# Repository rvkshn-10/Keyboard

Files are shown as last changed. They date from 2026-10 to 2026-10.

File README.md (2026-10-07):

# Keyboard 
Hello, this is a Keyboard Project which was my first time developing a PCB, after numerous errors and attempts, I finally got it done thanks to the Half Life Program at Hack Club. 
Firmware for the Arduino is in the firmware folder, while the PCB and Schematic files are in the main folder. Inside of the keyboard61 folder you can find the fabrication files necessary to print the actual circuit board. The layout, and pictures have also been put there.

Here are some images of my work!
Project image 1
Project image 2
Project image 3
Project image 4
Project image 5
Project image 6
Project image 7
Project image 8
Project image 9
Project image 10
Project image 11
Project image 12
Project image 13
Project image 14
Project image 15
Project image 16
Project image 17
Project image 18
Project image 19

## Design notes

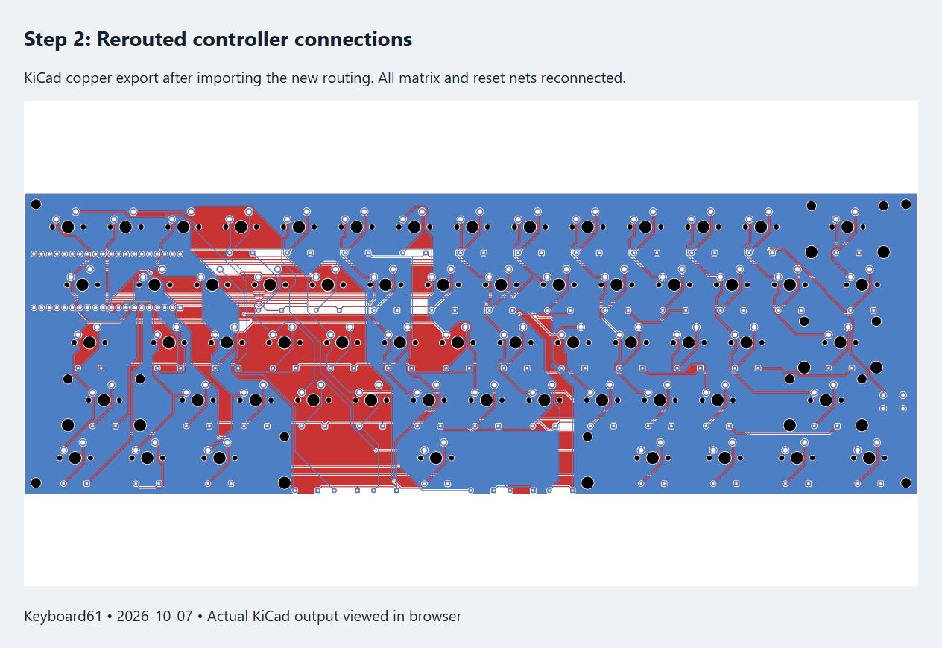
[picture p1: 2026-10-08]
keyboard61/inward-usb/screenshots/02-routing.jpg

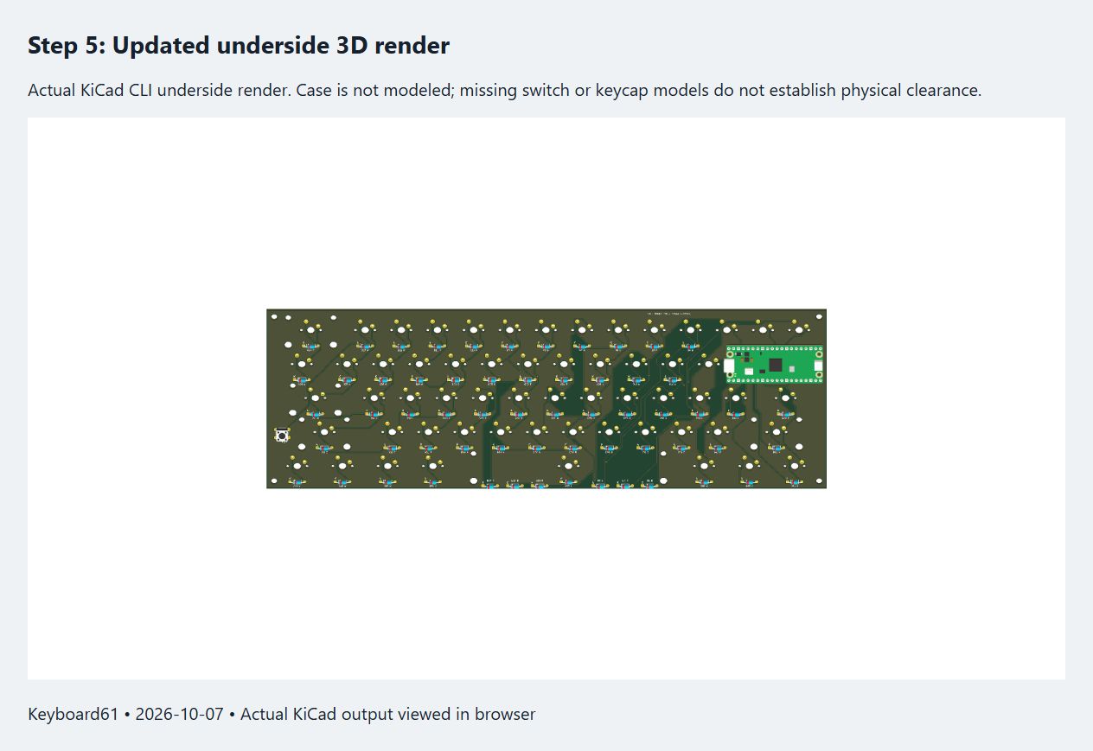
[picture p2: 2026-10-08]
keyboard61/inward-usb/screenshots/05-underside-3d.jpg

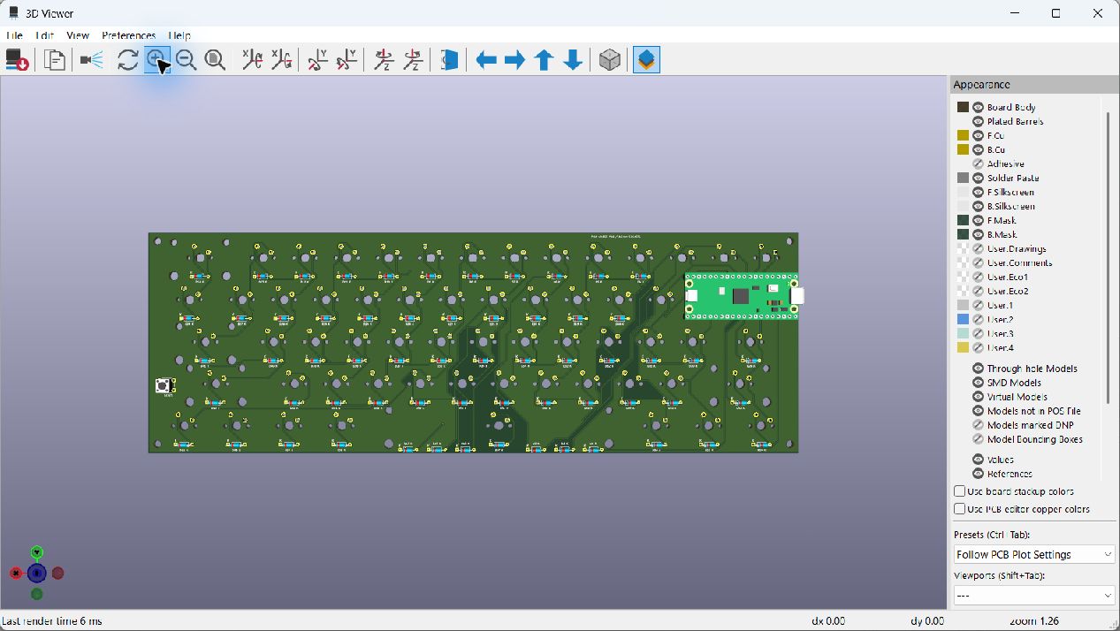
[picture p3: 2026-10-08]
keyboard61/compact-screenshots/02-finished-underside.jpg

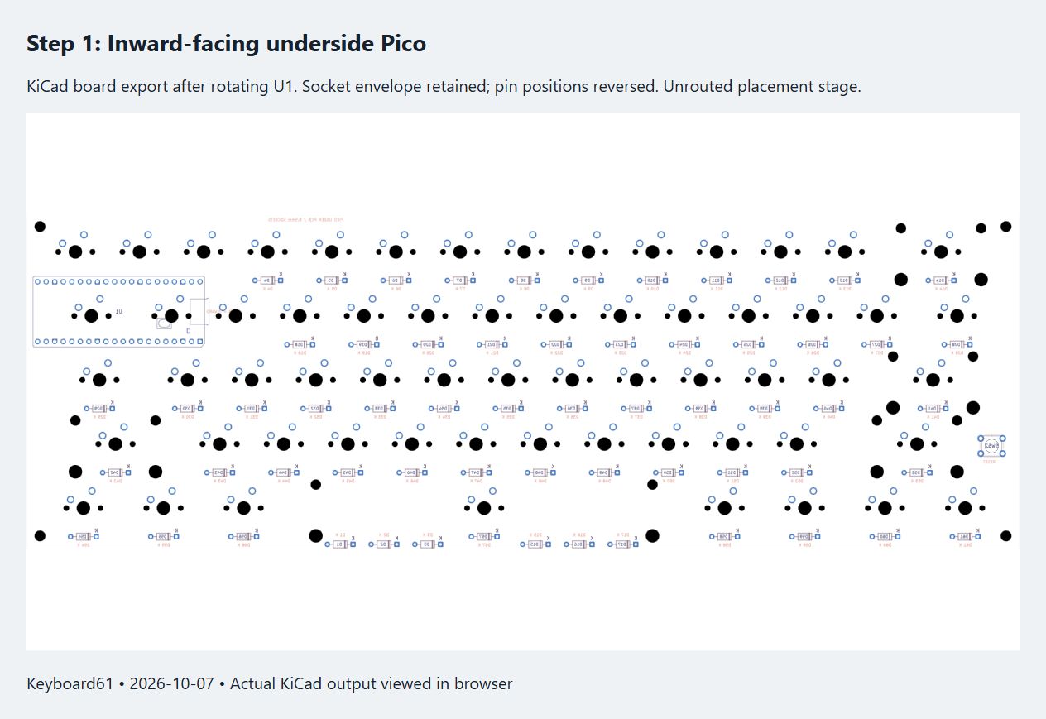
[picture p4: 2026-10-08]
keyboard61/inward-usb/screenshots/01-placement.jpg

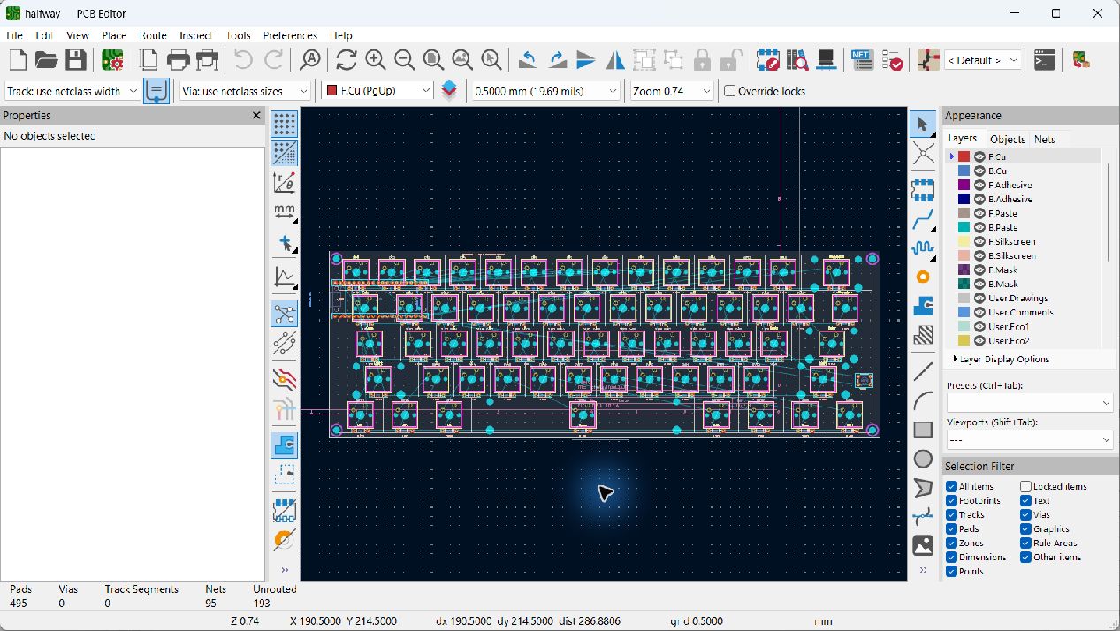
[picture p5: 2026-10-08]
keyboard61/compact-screenshots/01-placement.jpg

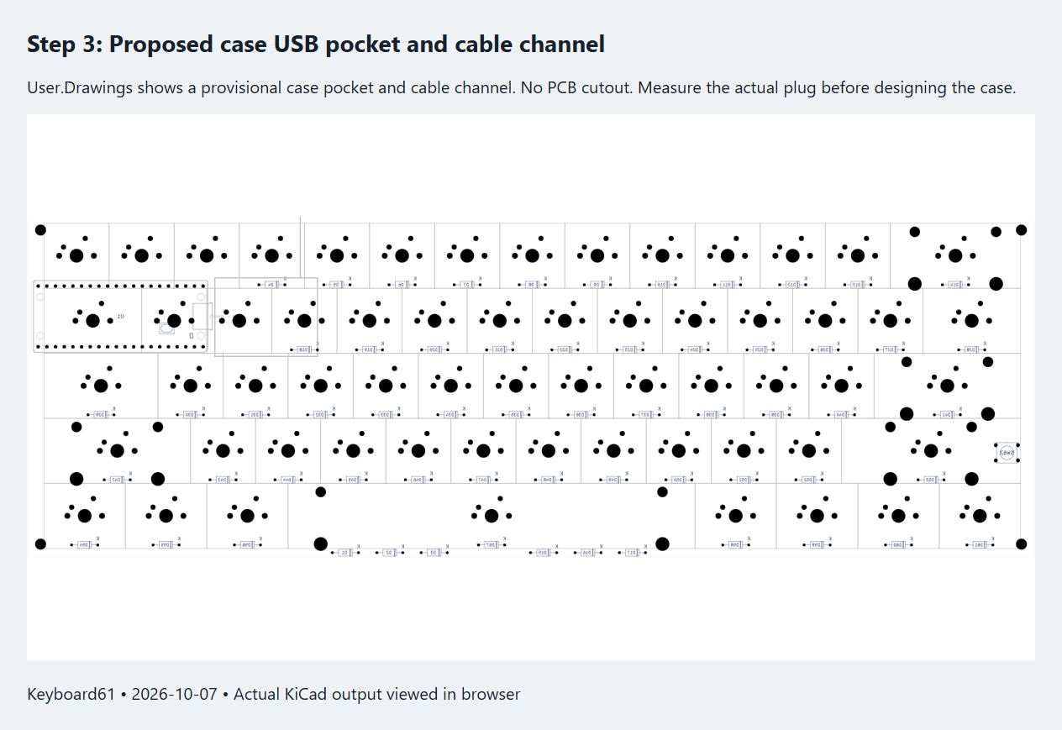
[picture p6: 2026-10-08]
keyboard61/inward-usb/screenshots/03-usb-pocket.jpg

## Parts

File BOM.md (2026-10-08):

# PC Keyboard – bill of materials

<!-- Generated by Half Life from project cmuvfkuo500di01qrszfxl69h. Edits here are overwritten on the next sync. -->
<!-- Generated: 2026-10-08T03:43:33.615Z -->

> [!NOTE]
> This parts list is mirrored from [Half Life](https://halflife.hackclub.com). Editing it here will not change the platform's copy, and the next sync overwrites this file.

| Week | Tier | Parts funding |
| --- | --- | --- |
| Week 1 | Tier 2 | $65.00 |

| Part | What it's for | Qty | Unit | Total | Vendor |
| --- | --- | --- | --- | --- | --- |
| [Keyboard PCB, Batch of 5](https://cart.jlcpcb.com/quote) | The PCB to control the keyboard | 1 | $31.15 | $31.15 | [JLCPCB](https://cart.jlcpcb.com/quote) |
| [onsemi 1N4148 DO-35 diode](https://www.digikey.com/en/products/detail/onsemi/1N4148/458603) | Prevent Keyboard from matrix ghosting | 61 | $0.04 | $2.44 | [Digikey](https://www.digikey.com/en/products/detail/onsemi/1N4148/458603) |
| [Raspberry Pi Pico H](https://www.digikey.com/en/products/detail/raspberry-pi/SC0917/16608257) | Scan the matrix, send USB outputs | 1 | $5.00 | $5.00 | [Digikey](https://www.digikey.com/en/products/detail/raspberry-pi/SC0917/16608257) |
| [Adafruit Pico female socket pair](https://www.digikey.com/en/products/detail/adafruit-industries-llc/5583/16688063) | Socket the Pico on the PCB | 1 | $0.95 | $0.95 | [Digikey](https://www.digikey.com/en/products/detail/adafruit-industries-llc/5583/16688063) |
| [Adafruit 4111 USB-A to Micro-B cable, 1 m](https://www.digikey.com/en/products/detail/adafruit-industries-llc/4111/9992197) | Connects the Pico to the PC | 1 | $3.95 | $3.95 | [DigiKey](https://www.digikey.com/en/products/detail/adafruit-industries-llc/4111/9992197) |
| **Parts subtotal** | — | — | — | **$43.49** | — |
| **Tax & shipping** | — | — | — | **$20.00** | — |
| **Total** | — | — | — | **$63.49** | — |

$1.51 left of the tier's funding.

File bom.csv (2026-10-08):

Part | Quantity | Unit Price | Total Price | Vendor | Vendor Name | Purpose | Specification | Price Status | Paid By
Keyboard PCB - batch of 5 | 1 | 31.15 | 31.15 | https://cart.jlcpcb.com/quote | JLCPCB | Connect the switches and Pico | keyboard61 compact underside-Pico revision; 295 x 100 mm; 2 layers; 1.6 mm FR4; 1 oz; green; lead-free HASL; 5 boards minimum; 1 used | USD 31.15 is the prior 295 x 168 mm size-based estimate; new 295 x 100 mm board requires a fresh fabrication quote; shipping and tax pending | Hack Club funding request
onsemi 1N4148 DO-35 diodes - 61-piece purchasing group | 1 | 2.57 | 2.57 | https://www.digikey.com/en/products/detail/onsemi/1N4148/458603 | DigiKey | Prevent keyboard matrix ghosting | Order 61 individual onsemi 1N4148 DO-35 diodes at USD 0.0422 each; grouped for cent-precision BOM import; 61 fitted; bend leads to 7.62 mm pitch | Listed USD price checked 2026-10-07; tax shipping and applicable tariffs excluded | Hack Club funding request
Raspberry Pi Pico H | 1 | 5.00 | 5.00 | https://www.digikey.com/en/products/detail/raspberry-pi/SC0917/16608257 | DigiKey | Scan the matrix and send USB key presses | SC0917; RP2040 original Pico H; pre-soldered male headers; micro-USB; matches existing Pico pin map | Listed USD price checked 2026-10-07; tax shipping and applicable tariffs excluded | Hack Club funding request
Adafruit Pico female socket pair | 1 | 0.95 | 0.95 | https://www.digikey.com/en/products/detail/adafruit-industries-llc/5583/16688063 | DigiKey | Socket the Pico on the PCB | Adafruit 5583; two standard-height 8.5 mm 1x20 female sockets; 2.54 mm pitch; mount on BACK; Pico H USB faces left; confirm actual enclosure and plug clearance | Listed USD price checked 2026-10-07; tax shipping and applicable tariffs excluded | Hack Club funding request

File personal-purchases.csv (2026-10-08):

Part | Quantity | Unit Price | Total Price | Vendor | Vendor Name | Purpose | Specification | Price Status | Paid By
Gateron Milky Yellow Pro V2 - pack of 70 | 1 | 19.99 | 19.99 | https://www.amazon.com/dp/B0BBPPP7HD | Amazon / CN GAMING | Detect each key press | 70 switches; 61 used and 9 spare; 5-pin PCB-mount MX stem; 50gf linear; soldered | USD price checked 2026-10-07; regular price; tax and shipping excluded | Personal purchase
SDYZ x XVX Gradient Green keycap set | 1 | 13.99 | 13.99 | https://www.amazon.com/dp/B0DNMV32L2 | Amazon / HITIME Shop | Provide surfaces for the 61 keys | Green; OEM doubleshot PBT; MX stems; standard ANSI 61-key sizes; 6.25u spacebar; regular non-Prime price | USD price checked 2026-10-07; regular price; tax and shipping excluded | Personal purchase
Chilkey WS Stupid snap-in stabilizer kit | 1 | 21.99 | 21.99 | https://www.amazon.com/dp/B0D2KMVVL3 | Amazon / Meletrix Direct | Support the five wide keys | Select 1.6 mm PCB version; four 2u and one 6.25u stabilizers required; use 6.25u wire; PCB snap-in; confirm hole geometry before fabrication | USD price checked 2026-10-07; regular price; tax and shipping excluded | Personal purchase
YOUFEN reset buttons - pack of 126 | 1 | 4.66 | 4.66 | https://www.amazon.com/dp/B0D5M2ZNSL | Amazon | Connect RUN to ground to reset the Pico | 6 x 6 x 5 mm four-pin through-hole tactile; one used; 125 spare; verify pin pitch against SW_PUSH_6mm | USD price checked 2026-10-07; regular price; tax and shipping excluded | Personal purchase
M3 nylon standoff and fastener kit - 600 pieces | 1 | 6.99 | 6.99 | https://www.amazon.com/dp/B0G3XCGSNV | Amazon / YILEGOU | Support the PCB above the desk | M3 nylon screws nuts and spacers; 6 to 20 mm lengths; four mounting holes; use suitable spacers for underside diode clearance; future custom enclosure deferred | USD price checked 2026-10-07; regular price; tax and shipping excluded | Personal purchase
Micro USB data cable - 3 ft | 1 | 5.99 | 5.99 | https://www.amazon.com/dp/B0BLL6BPGC | Amazon / Wancheng store | Power the Pico and carry USB keyboard data | Black; 3 ft; USB-A to micro-B; USB 2.0 480Mbps data sync; regular non-Prime buy-box price; one cable | USD price checked 2026-10-07; regular price; tax and shipping excluded | Personal purchase

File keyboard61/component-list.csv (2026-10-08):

Reference | Value | Footprint
D1 | 1N4148 | Diode_THT:D_DO-35_SOD27_P7.62mm_Horizontal
D2 | 1N4148 | Diode_THT:D_DO-35_SOD27_P7.62mm_Horizontal
D3 | 1N4148 | Diode_THT:D_DO-35_SOD27_P7.62mm_Horizontal
D4 | 1N4148 | Diode_THT:D_DO-35_SOD27_P7.62mm_Horizontal
D5 | 1N4148 | Diode_THT:D_DO-35_SOD27_P7.62mm_Horizontal
D6 | 1N4148 | Diode_THT:D_DO-35_SOD27_P7.62mm_Horizontal
D7 | 1N4148 | Diode_THT:D_DO-35_SOD27_P7.62mm_Horizontal
D8 | 1N4148 | Diode_THT:D_DO-35_SOD27_P7.62mm_Horizontal
D9 | 1N4148 | Diode_THT:D_DO-35_SOD27_P7.62mm_Horizontal
D10 | 1N4148 | Diode_THT:D_DO-35_SOD27_P7.62mm_Horizontal
D11 | 1N4148 | Diode_THT:D_DO-35_SOD27_P7.62mm_Horizontal
D12 | 1N4148 | Diode_THT:D_DO-35_SOD27_P7.62mm_Horizontal
D13 | 1N4148 | Diode_THT:D_DO-35_SOD27_P7.62mm_Horizontal
D14 | 1N4148 | Diode_THT:D_DO-35_SOD27_P7.62mm_Horizontal
D15 | 1N4148 | Diode_THT:D_DO-35_SOD27_P7.62mm_Horizontal
D16 | 1N4148 | Diode_THT:D_DO-35_SOD27_P7.62mm_Horizontal
D17 | 1N4148 | Diode_THT:D_DO-35_SOD27_P7.62mm_Horizontal
D18 | 1N4148 | Diode_THT:D_DO-35_SOD27_P7.62mm_Horizontal
D19 | 1N4148 | Diode_THT:D_DO-35_SOD27_P7.62mm_Horizontal
D20 | 1N4148 | Diode_THT:D_DO-35_SOD27_P7.62mm_Horizontal
D21 | 1N4148 | Diode_THT:D_DO-35_SOD27_P7.62mm_Horizontal
D22 | 1N4148 | Diode_THT:D_DO-35_SOD27_P7.62mm_Horizontal
D23 | 1N4148 | Diode_THT:D_DO-35_SOD27_P7.62mm_Horizontal
D24 | 1N4148 | Diode_THT:D_DO-35_SOD27_P7.62mm_Horizontal
D25 | 1N4148 | Diode_THT:D_DO-35_SOD27_P7.62mm_Horizontal
D26 | 1N4148 | Diode_THT:D_DO-35_SOD27_P7.62mm_Horizontal
D27 | 1N4148 | Diode_THT:D_DO-35_SOD27_P7.62mm_Horizontal
D28 | 1N4148 | Diode_THT:D_DO-35_SOD27_P7.62mm_Horizontal
D29 | 1N4148 | Diode_THT:D_DO-35_SOD27_P7.62mm_Horizontal
D30 | 1N4148 | Diode_THT:D_DO-35_SOD27_P7.62mm_Horizontal
D31 | 1N4148 | Diode_THT:D_DO-35_SOD27_P7.62mm_Horizontal
D32 | 1N4148 | Diode_THT:D_DO-35_SOD27_P7.62mm_Horizontal
D33 | 1N4148 | Diode_THT:D_DO-35_SOD27_P7.62mm_Horizontal
D34 | 1N4148 | Diode_THT:D_DO-35_SOD27_P7.62mm_Horizontal
D35 | 1N4148 | Diode_THT:D_DO-35_SOD27_P7.62mm_Horizontal
D36 | 1N4148 | Diode_THT:D_DO-35_SOD27_P7.62mm_Horizontal
D37 | 1N4148 | Diode_THT:D_DO-35_SOD27_P7.62mm_Horizontal
D38 | 1N4148 | Diode_THT:D_DO-35_SOD27_P7.62mm_Horizontal
D39 | 1N4148 | Diode_THT:D_DO-35_SOD27_P7.62mm_Horizontal
D40 | 1N4148 | Diode_THT:D_DO-35_SOD27_P7.62mm_Horizontal
D41 | 1N4148 | Diode_THT:D_DO-35_SOD27_P7.62mm_Horizontal
D42 | 1N4148 | Diode_THT:D_DO-35_SOD27_P7.62mm_Horizontal
D43 | 1N4148 | Diode_THT:D_DO-35_SOD27_P7.62mm_Horizontal
D44 | 1N4148 | Diode_THT:D_DO-35_SOD27_P7.62mm_Horizontal
D45 | 1N4148 | Diode_THT:D_DO-35_SOD27_P7.62mm_Horizontal
D46 | 1N4148 | Diode_THT:D_DO-35_SOD27_P7.62mm_Horizontal
D47 | 1N4148 | Diode_THT:D_DO-35_SOD27_P7.62mm_Horizontal
D48 | 1N4148 | Diode_THT:D_DO-35_SOD27_P7.62mm_Horizontal
D49 | 1N4148 | Diode_THT:D_DO-35_SOD27_P7.62mm_Horizontal
D50 | 1N4148 | Diode_THT:D_DO-35_SOD27_P7.62mm_Horizontal
D51 | 1N4148 | Diode_THT:D_DO-35_SOD27_P7.62mm_Horizontal
D52 | 1N4148 | Diode_THT:D_DO-35_SOD27_P7.62mm_Horizontal
D53 | 1N4148 | Diode_THT:D_DO-35_SOD27_P7.62mm_Horizontal
D54 | 1N4148 | Diode_THT:D_DO-35_SOD27_P7.62mm_Horizontal
D55 | 1N4148 | Diode_THT:D_DO-35_SOD27_P7.62mm_Horizontal
D56 | 1N4148 | Diode_THT:D_DO-35_SOD27_P7.62mm_Horizontal
D57 | 1N4148 | Diode_THT:D_DO-35_SOD27_P7.62mm_Horizontal
D58 | 1N4148 | Diode_THT:D_DO-35_SOD27_P7.62mm_Horizontal
D59 | 1N4148 | Diode_THT:D_DO-35_SOD27_P7.62mm_Horizontal
D60 | 1N4148 | Diode_THT:D_DO-35_SOD27_P7.62mm_Horizontal
D61 | 1N4148 | Diode_THT:D_DO-35_SOD27_P7.62mm_Horizontal
SW1 | Esc | Button_Switch_Keyboard:SW_Cherry_MX_1.00u_PCB
SW2 | 1 | Button_Switch_Keyboard:SW_Cherry_MX_1.00u_PCB
SW3 | 2 | Button_Switch_Keyboard:SW_Cherry_MX_1.00u_PCB
SW4 | 3 | Button_Switch_Keyboard:SW_Cherry_MX_1.00u_PCB
SW5 | 4 | Button_Switch_Keyboard:SW_Cherry_MX_1.00u_PCB
SW6 | 5 | Button_Switch_Keyboard:SW_Cherry_MX_1.00u_PCB
SW7 | 6 | Button_Switch_Keyboard:SW_Cherry_MX_1.00u_PCB
SW8 | 7 | Button_Switch_Keyboard:SW_Cherry_MX_1.00u_PCB
SW9 | 8 | Button_Switch_Keyboard:SW_Cherry_MX_1.00u_PCB
SW10 | 9 | Button_Switch_Keyboard:SW_Cherry_MX_1.00u_PCB
SW11 | 0 | Button_Switch_Keyboard:SW_Cherry_MX_1.00u_PCB
SW12 | - | Button_Switch_Keyboard:SW_Cherry_MX_1.00u_PCB
SW13 | = | Button_Switch_Keyboard:SW_Cherry_MX_1.00u_PCB
SW14 | Backspace | Button_Switch_Keyboard:SW_Cherry_MX_2.00u_PCB
SW15 | Tab | Keyboard61:SW_Cherry_MX_1.50u_PCB_SocketClearance
SW16 | Q | Keyboard61:SW_Cherry_MX_1.00u_PCB_SocketClearance
SW17 | W | Button_Switch_Keyboard:SW_Cherry_MX_1.00u_PCB
SW18 | E | Button_Switch_Keyboard:SW_Cherry_MX_1.00u_PCB
SW19 | R | Button_Switch_Keyboard:SW_Cherry_MX_1.00u_PCB
SW20 | T | Button_Switch_Keyboard:SW_Cherry_MX_1.00u_PCB
SW21 | Y | Button_Switch_Keyboard:SW_Cherry_MX_1.00u_PCB
SW22 | U | Button_Switch_Keyboard:SW_Cherry_MX_1.00u_PCB
SW23 | I | Button_Switch_Keyboard:SW_Cherry_MX_1.00u_PCB
SW24 | O | Button_Switch_Keyboard:SW_Cherry_MX_1.00u_PCB
SW25 | P | Button_Switch_Keyboard:SW_Cherry_MX_1.00u_PCB
SW26 | [ | Button_Switch_Keyboard:SW_Cherry_MX_1.00u_PCB
SW27 | ] | Button_Switch_Keyboard:SW_Cherry_MX_1.00u_PCB
SW28 | Backslash | Button_Switch_Keyboard:SW_Cherry_MX_1.50u_PCB
SW29 | Caps | Button_Switch_Keyboard:SW_Cherry_MX_1.75u_PCB
SW30 | A | Button_Switch_Keyboard:SW_Cherry_MX_1.00u_PCB
SW31 | S | Button_Switch_Keyboard:SW_Cherry_MX_1.00u_PCB
SW32 | D | Button_Switch_Keyboard:SW_Cherry_MX_1.00u_PCB
SW33 | F | Button_Switch_Keyboard:SW_Cherry_MX_1.00u_PCB
SW34 | G | Button_Switch_Keyboard:SW_Cherry_MX_1.00u_PCB
SW35 | H | Button_Switch_Keyboard:SW_Cherry_MX_1.00u_PCB
SW36 | J | Button_Switch_Keyboard:SW_Cherry_MX_1.00u_PCB
SW37 | K | Button_Switch_Keyboard:SW_Cherry_MX_1.00u_PCB
SW38 | L | Button_Switch_Keyboard:SW_Cherry_MX_1.00u_PCB
SW39 | ; | Button_Switch_Keyboard:SW_Cherry_MX_1.00u_PCB
SW40 | Quote | Button_Switch_Keyboard:SW_Cherry_MX_1.00u_PCB
SW41 | Enter | Button_Switch_Keyboard:SW_Cherry_MX_2.25u_PCB
SW42 | LShift | Button_Switch_Keyboard:SW_Cherry_MX_2.25u_PCB
SW43 | Z | Button_Switch_Keyboard:SW_Cherry_MX_1.00u_PCB
SW44 | X | Button_Switch_Keyboard:SW_Cherry_MX_1.00u_PCB
SW45 | C | Button_Switch_Keyboard:SW_Cherry_MX_1.00u_PCB
SW46 | V | Button_Switch_Keyboard:SW_Cherry_MX_1.00u_PCB
SW47 | B | Button_Switch_Keyboard:SW_Cherry_MX_1.00u_PCB
SW48 | N | Button_Switch_Keyboard:SW_Cherry_MX_1.00u_PCB
SW49 | M | Button_Switch_Keyboard:SW_Cherry_MX_1.00u_PCB
SW50 | , | Button_Switch_Keyboard:SW_Cherry_MX_1.00u_PCB
SW51 | . | Button_Switch_Keyboard:SW_Cherry_MX_1.00u_PCB
SW52 | / | Button_Switch_Keyboard:SW_Cherry_MX_1.00u_PCB
SW53 | RShift | Button_Switch_Keyboard:SW_Cherry_MX_2.75u_PCB
SW54 | LCtrl | Button_Switch_Keyboard:SW_Cherry_MX_1.25u_PCB
SW55 | LWin | Button_Switch_Keyboard:SW_Cherry_MX_1.25u_PCB
SW56 | LAlt | Button_Switch_Keyboard:SW_Cherry_MX_1.25u_PCB
SW57 | Space | Button_Switch_Keyboard:SW_Cherry_MX_6.25u_PCB
SW58 | RAlt | Button_Switch_Keyboard:SW_Cherry_MX_1.25u_PCB
SW59 | Fn | Button_Switch_Keyboard:SW_Cherry_MX_1.25u_PCB
SW60 | Menu | Button_Switch_Keyboard:SW_Cherry_MX_1.25u_PCB
SW61 | RCtrl | Button_Switch_Keyboard:SW_Cherry_MX_1.25u_PCB
SW62 | RESET | Button_Switch_THT:SW_PUSH_6mm
U1 | Raspberry Pi Pico | Keyboard61:Pico_H_Bottom_Sockets_8_5mm

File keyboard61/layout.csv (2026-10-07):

reference | diode | key | row | col | x_u | y_u | width_u | footprint
SW1 | D1 | Esc | 0 | 0 | 0 | 0 | 1 | Button_Switch_Keyboard:SW_Cherry_MX_1.00u_PCB
SW2 | D2 | 1 | 0 | 1 | 1 | 0 | 1 | Button_Switch_Keyboard:SW_Cherry_MX_1.00u_PCB
SW3 | D3 | 2 | 0 | 2 | 2 | 0 | 1 | Button_Switch_Keyboard:SW_Cherry_MX_1.00u_PCB
SW4 | D4 | 3 | 0 | 3 | 3 | 0 | 1 | Button_Switch_Keyboard:SW_Cherry_MX_1.00u_PCB
SW5 | D5 | 4 | 0 | 4 | 4 | 0 | 1 | Button_Switch_Keyboard:SW_Cherry_MX_1.00u_PCB
SW6 | D6 | 5 | 0 | 5 | 5 | 0 | 1 | Button_Switch_Keyboard:SW_Cherry_MX_1.00u_PCB
SW7 | D7 | 6 | 0 | 6 | 6 | 0 | 1 | Button_Switch_Keyboard:SW_Cherry_MX_1.00u_PCB
SW8 | D8 | 7 | 0 | 7 | 7 | 0 | 1 | Button_Switch_Keyboard:SW_Cherry_MX_1.00u_PCB
SW9 | D9 | 8 | 0 | 8 | 8 | 0 | 1 | Button_Switch_Keyboard:SW_Cherry_MX_1.00u_PCB
SW10 | D10 | 9 | 0 | 9 | 9 | 0 | 1 | Button_Switch_Keyboard:SW_Cherry_MX_1.00u_PCB
SW11 | D11 | 0 | 0 | 10 | 10 | 0 | 1 | Button_Switch_Keyboard:SW_Cherry_MX_1.00u_PCB
SW12 | D12 | - | 0 | 11 | 11 | 0 | 1 | Button_Switch_Keyboard:SW_Cherry_MX_1.00u_PCB
SW13 | D13 | = | 0 | 12 | 12 | 0 | 1 | Button_Switch_Keyboard:SW_Cherry_MX_1.00u_PCB
SW14 | D14 | Backspace | 0 | 13 | 13 | 0 | 2 | Button_Switch_Keyboard:SW_Cherry_MX_2.00u_PCB
SW15 | D15 | Tab | 1 | 0 | 0 | 1 | 1.5 | Button_Switch_Keyboard:SW_Cherry_MX_1.50u_PCB
SW16 | D16 | Q | 1 | 1 | 1.5 | 1 | 1 | Button_Switch_Keyboard:SW_Cherry_MX_1.00u_PCB
SW17 | D17 | W | 1 | 2 | 2.5 | 1 | 1 | Button_Switch_Keyboard:SW_Cherry_MX_1.00u_PCB
SW18 | D18 | E | 1 | 3 | 3.5 | 1 | 1 | Button_Switch_Keyboard:SW_Cherry_MX_1.00u_PCB
SW19 | D19 | R | 1 | 4 | 4.5 | 1 | 1 | Button_Switch_Keyboard:SW_Cherry_MX_1.00u_PCB
SW20 | D20 | T | 1 | 5 | 5.5 | 1 | 1 | Button_Switch_Keyboard:SW_Cherry_MX_1.00u_PCB
SW21 | D21 | Y | 1 | 6 | 6.5 | 1 | 1 | Button_Switch_Keyboard:SW_Cherry_MX_1.00u_PCB
SW22 | D22 | U | 1 | 7 | 7.5 | 1 | 1 | Button_Switch_Keyboard:SW_Cherry_MX_1.00u_PCB
SW23 | D23 | I | 1 | 8 | 8.5 | 1 | 1 | Button_Switch_Keyboard:SW_Cherry_MX_1.00u_PCB
SW24 | D24 | O | 1 | 9 | 9.5 | 1 | 1 | Button_Switch_Keyboard:SW_Cherry_MX_1.00u_PCB
SW25 | D25 | P | 1 | 10 | 10.5 | 1 | 1 | Button_Switch_Keyboard:SW_Cherry_MX_1.00u_PCB
SW26 | D26 | [ | 1 | 11 | 11.5 | 1 | 1 | Button_Switch_Keyboard:SW_Cherry_MX_1.00u_PCB
SW27 | D27 | ] | 1 | 12 | 12.5 | 1 | 1 | Button_Switch_Keyboard:SW_Cherry_MX_1.00u_PCB
SW28 | D28 | Backslash | 1 | 13 | 13.5 | 1 | 1.5 | Button_Switch_Keyboard:SW_Cherry_MX_1.50u_PCB
SW29 | D29 | Caps | 2 | 0 | 0 | 2 | 1.75 | Button_Switch_Keyboard:SW_Cherry_MX_1.75u_PCB
SW30 | D30 | A | 2 | 1 | 1.75 | 2 | 1 | Button_Switch_Keyboard:SW_Cherry_MX_1.00u_PCB
SW31 | D31 | S | 2 | 2 | 2.75 | 2 | 1 | Button_Switch_Keyboard:SW_Cherry_MX_1.00u_PCB
SW32 | D32 | D | 2 | 3 | 3.75 | 2 | 1 | Button_Switch_Keyboard:SW_Cherry_MX_1.00u_PCB
SW33 | D33 | F | 2 | 4 | 4.75 | 2 | 1 | Button_Switch_Keyboard:SW_Cherry_MX_1.00u_PCB
SW34 | D34 | G | 2 | 5 | 5.75 | 2 | 1 | Button_Switch_Keyboard:SW_Cherry_MX_1.00u_PCB
SW35 | D35 | H | 2 | 6 | 6.75 | 2 | 1 | Button_Switch_Keyboard:SW_Cherry_MX_1.00u_PCB
SW36 | D36 | J | 2 | 7 | 7.75 | 2 | 1 | Button_Switch_Keyboard:SW_Cherry_MX_1.00u_PCB
SW37 | D37 | K | 2 | 8 | 8.75 | 2 | 1 | Button_Switch_Keyboard:SW_Cherry_MX_1.00u_PCB
SW38 | D38 | L | 2 | 9 | 9.75 | 2 | 1 | Button_Switch_Keyboard:SW_Cherry_MX_1.00u_PCB
SW39 | D39 | ; | 2 | 10 | 10.75 | 2 | 1 | Button_Switch_Keyboard:SW_Cherry_MX_1.00u_PCB
SW40 | D40 | Quote | 2 | 11 | 11.75 | 2 | 1 | Button_Switch_Keyboard:SW_Cherry_MX_1.00u_PCB
SW41 | D41 | Enter | 2 | 12 | 12.75 | 2 | 2.25 | Button_Switch_Keyboard:SW_Cherry_MX_2.25u_PCB
SW42 | D42 | LShift | 3 | 0 | 0 | 3 | 2.25 | Button_Switch_Keyboard:SW_Cherry_MX_2.25u_PCB
SW43 | D43 | Z | 3 | 1 | 2.25 | 3 | 1 | Button_Switch_Keyboard:SW_Cherry_MX_1.00u_PCB
SW44 | D44 | X | 3 | 2 | 3.25 | 3 | 1 | Button_Switch_Keyboard:SW_Cherry_MX_1.00u_PCB
SW45 | D45 | C | 3 | 3 | 4.25 | 3 | 1 | Button_Switch_Keyboard:SW_Cherry_MX_1.00u_PCB
SW46 | D46 | V | 3 | 4 | 5.25 | 3 | 1 | Button_Switch_Keyboard:SW_Cherry_MX_1.00u_PCB
SW47 | D47 | B | 3 | 5 | 6.25 | 3 | 1 | Button_Switch_Keyboard:SW_Cherry_MX_1.00u_PCB
SW48 | D48 | N | 3 | 6 | 7.25 | 3 | 1 | Button_Switch_Keyboard:SW_Cherry_MX_1.00u_PCB
SW49 | D49 | M | 3 | 7 | 8.25 | 3 | 1 | Button_Switch_Keyboard:SW_Cherry_MX_1.00u_PCB
SW50 | D50 | , | 3 | 8 | 9.25 | 3 | 1 | Button_Switch_Keyboard:SW_Cherry_MX_1.00u_PCB
SW51 | D51 | . | 3 | 9 | 10.25 | 3 | 1 | Button_Switch_Keyboard:SW_Cherry_MX_1.00u_PCB
SW52 | D52 | / | 3 | 10 | 11.25 | 3 | 1 | Button_Switch_Keyboard:SW_Cherry_MX_1.00u_PCB
SW53 | D53 | RShift | 3 | 11 | 12.25 | 3 | 2.75 | Button_Switch_Keyboard:SW_Cherry_MX_2.75u_PCB
SW54 | D54 | LCtrl | 4 | 0 | 0 | 4 | 1.25 | Button_Switch_Keyboard:SW_Cherry_MX_1.25u_PCB
SW55 | D55 | LWin | 4 | 1 | 1.25 | 4 | 1.25 | Button_Switch_Keyboard:SW_Cherry_MX_1.25u_PCB
SW56 | D56 | LAlt | 4 | 2 | 2.5 | 4 | 1.25 | Button_Switch_Keyboard:SW_Cherry_MX_1.25u_PCB
SW57 | D57 | Space | 4 | 3 | 3.75 | 4 | 6.25 | Button_Switch_Keyboard:SW_Cherry_MX_6.25u_PCB
SW58 | D58 | RAlt | 4 | 4 | 10.0 | 4 | 1.25 | Button_Switch_Keyboard:SW_Cherry_MX_1.25u_PCB
SW59 | D59 | Fn | 4 | 5 | 11.25 | 4 | 1.25 | Button_Switch_Keyboard:SW_Cherry_MX_1.25u_PCB
SW60 | D60 | Menu | 4 | 6 | 12.5 | 4 | 1.25 | Button_Switch_Keyboard:SW_Cherry_MX_1.25u_PCB
SW61 | D61 | RCtrl | 4 | 7 | 13.75 | 4 | 1.25 | Button_Switch_Keyboard:SW_Cherry_MX_1.25u_PCB

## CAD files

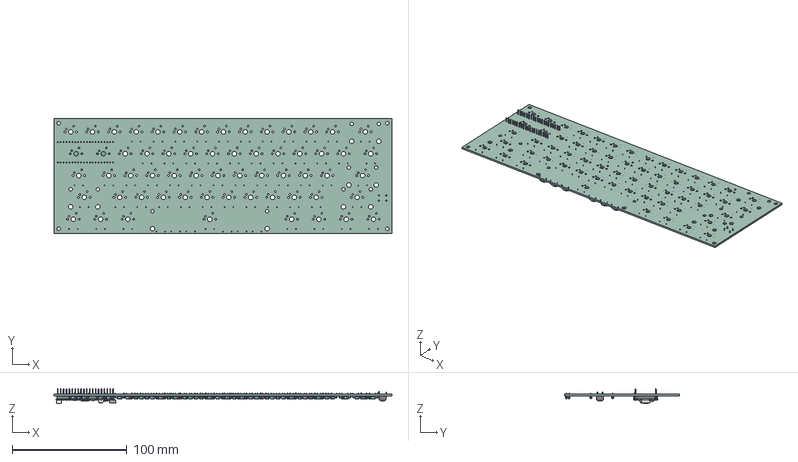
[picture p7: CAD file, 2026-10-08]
keyboard61/keyboard61.step
295.0 x 100.0 x 12.8 mm
D_DO-35_SOD27_P7.62mm_Horizontal x 61
RaspberryPi_Pico_H_Module_KiCad
RaspberryPi_Pico_Header_DIP-40_H2.54mm_KiCad
SW_PUSH_6mm
finished_PCB

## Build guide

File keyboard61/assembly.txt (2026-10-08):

PCB revision: compact underside Pico, 2026-10-07
Board: 295 x 100 mm, x45..340 y113..213, 1.6 mm FR4.
61 original key positions and GPIO assignments preserved. Firmware unchanged.
Pico H and reset switch fitted on BACK. Switches on FRONT.
Fit the two standard-height 8.5 mm 1x20 female sockets on BACK, matching pad 1.
Pico USB faces RIGHT, toward the keyboard center, underneath the PCB.
No USB extension cable is required by this revision.
Plan an accessible pocket in the CASE underside for inserting a normal Micro-B plug.
The proposed channel leads toward the edge above the number keys.
User.Drawings is a case-planning sketch, not copper or a PCB cutout.
Pocket envelope and channel are provisional; measure the real plug before case design.
Keep the cable and slack clear of switch pins, diode leads and mounting fasteners.
Allow cable bend radius and strain relief; never force a bend directly at the connector.
Leave at least 15 mm below the keyboard PCB as a preliminary enclosure allowance;
verify the actual Pico, USB plug and socket assembly before making the case.
Diodes D1,D2,D3,D15,D16,D17 remain beneath the spacebar area; follow K marks.
Underside Pico BOOTSEL and reset must remain accessible through the case.
KiCad DRC: 0 violations, 0 unconnected, 0 schematic parity issues; no exclusions.
KiCad schematic ERC: 0 violations. Hardware has not been assembled or tested.
PCB fabrication price and shipping must be re-quoted for the new dimensions.

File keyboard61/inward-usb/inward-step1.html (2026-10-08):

# Step 1: Inward-facing underside Pico

KiCad board export after rotating U1. Socket envelope retained; pin positions reversed. Unrouted placement stage.



Keyboard61 • 2026-10-07 • Actual KiCad output viewed in browser

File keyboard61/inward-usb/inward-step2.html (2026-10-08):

# Step 2: Rerouted controller connections

KiCad copper export after importing the new routing. All matrix and reset nets reconnected.



Keyboard61 • 2026-10-07 • Actual KiCad output viewed in browser

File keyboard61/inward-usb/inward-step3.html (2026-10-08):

# Step 3: Proposed case USB pocket and cable channel

User.Drawings shows a provisional case pocket and cable channel. No PCB cutout. Measure the actual plug before designing the case.



Keyboard61 • 2026-10-07 • Actual KiCad output viewed in browser

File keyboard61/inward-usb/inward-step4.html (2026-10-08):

# Step 4: KiCad electrical and layout checks

Actual KiCad CLI check results from the revised board and schematic. Default ignored check categories remain listed in the JSON report.

KiCad 10.0.6
PCB DRC: 0 violations
Unconnected items: 0
Schematic parity: 0 issues

ERC report (2026-10-07T20:56:49, Encoding UTF8)
Report includes: Errors, Warnings

***** Sheet /

 ** ERC messages: 0  Errors 0  Warnings 0

 ** Ignored checks:
    - Global label only appears once in the schematic
    - Four connection points are joined together
    - SPICE model issue
    - Assigned footprint doesn't match footprint filters

Keyboard61 • 2026-10-07 • Actual KiCad output viewed in browser

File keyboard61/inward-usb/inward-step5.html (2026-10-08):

# Step 5: Updated underside 3D render

Actual KiCad CLI underside render. Case is not modeled; missing switch or keycap models do not establish physical clearance.

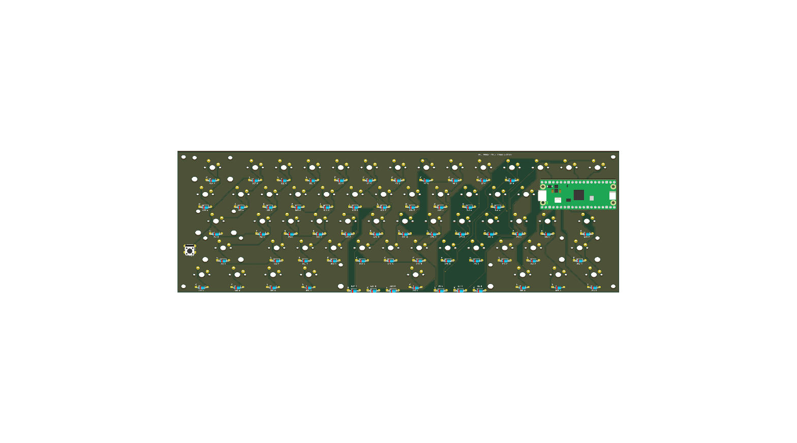
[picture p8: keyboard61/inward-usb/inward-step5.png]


Keyboard61 • 2026-10-07 • Actual KiCad output viewed in browser

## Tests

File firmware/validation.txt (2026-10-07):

PASS: A press and release
PASS: Shift+A and release
PASS: Fn+1 sends F1
PASS: Fn+I sends Up
PASS: Fn released before held F1
PASS: Unused matrix slot sends nothing
PASS: Menu key usage 0x65
PASS: 19 GPIO pins, COL2ROW, 61 occupied / 9 unused, 2 x 70 keymaps
Desktop simulation only; Pico USB, wiring and debounce require hardware testing.

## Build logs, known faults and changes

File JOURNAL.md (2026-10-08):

# PC Keyboard – devlog

<!-- Generated by Half Life from project cmuvfkuo500di01qrszfxl69h. Edits here are overwritten on the next sync. -->
<!-- Generated: 2026-10-08T03:15:25.698Z -->

> [!NOTE]
> This devlog is mirrored from [Half Life](https://halflife.hackclub.com). Editing it here will not change the platform's copy, and the next sync overwrites this file.

> A QWERTY wiredkeyboard

| Week | Tier | Hours logged | Entries |
| --- | --- | --- | --- |
| Week 1 | Tier 2 | 26.5h | 3 |

## Contents

1. [2026-10-06 – October 6](#2026-10-06-october-6)
2. [2026-10-07 – October 7](#2026-10-07-october-7)
3. [2026-10-07 – October 8](#2026-10-07-october-8)

## Design

### 2026-10-06 – October 6

**9.5h**

October 6

Though this was my first time designing a PCB, I still ended up creating a very basic Schematic. I originally began by following a GitHub tutorial, but that got quickly got too confusing, so I restarted  and began with finding KiCad Footprint Libraries and figuring out the electronics theory.

01-matrix-research
This was the Matrix Research I had to complete

To find the Libraries, I had to hunt down custom ones for Cherry MX switches, looking up the dimensions of a 1U keycap spacing, and looking into the pinout of an Arduino Pro Micro, but I later changed this to a Raspberry Pi



To understand the electronics theory, I had to research Keyboard matric functions, I also learned that I needed a 1N4148 diode next to every single switch to prevent something called ghosting. I also needed to know which way the electrical current flows in the PCB. I also learned how to use Global Labels to keep nets clean.


I also completed the 61 key ANSI layout as part of the placement plan along with matrix coordinate on each key

Later I found out that I didn't need a custom library, so I used the kicad ones, so I installed the kicad footprint verification


It took me a while to get to this stage at the pace I was working, and this was my first switch and anti-ghosting diode, and I followed the same method for each key


My next step was the number keys of 14 switch diode pairs, following the same COL to switch to diode anode; diode cathode to ROW


I later individually created each of the following keys and typed up the following information to specify which was which


My next step was  working with the Raspberry Pi Pico Controller and GPIO net labels, where I attached all labels and rows


By this point after many errors I made accidentally and going back and forth, I completed the full schematic


I later realized I missed something, I had to set up the Reset circuit and firmware flashing mode to use the onboard BOOTSEL button


### 2026-10-07 – October 7

**10h**

October 7

Now I began the actual PCB Portion. For PCB Layout, routing, and vias. I placed grid components, set up custom user grids and manual trace routing. I had to figure out how to route lines on both the front and back copper layers and sue plated holes (vias) to leapfrog the intersecting wires without short circuiting the board. I next had to do DRC Troubleshooting and Manufacturing setup, I threw quite a bit of errors, so I had to define an Edge.Cuts layer to outline the physical board, and I manually set up a copper filled zone to isolate electrical traces


I created my board outline, and the space above is reserved for the controller, the boundary was 295x168mm


I created my first switch row of 14 footprints using 19.05mm key spacing


Next I completed the remaining 61 switches in ANSI layout including the spacebar where the key is the center.


One 1N4148 diode was placed on each switch, on the back of the board between key rows, this is to prevent ghost key presses, an issue that arised for many other people that completed this project


I added the Pico footprint, reset button, and 4 3.2mm mounting holes. I still need to plan to create a casing for the keyboard based on this


Copper tracks were added between each switch and the diode, these are the individual key connections before the shared matrix wiring is completed


With this step I achieved complete signal routing as row and column connections were routed to Pico across front and back copper layers. The vias connect tracks between layers where they were needed


Filled ground planes on both sides of the PCB. KiCad did leave some clearance around unrelated tracks and pads. Apparently the thermal connections link ground pads to the pours while making the pads easier to solder


I created a Key legend, board identification, assembly instructions to the silkscreen layers. After this there were some errors, which I ended up fixing


KiCad displayed the PCB in it's 3D viewer. For some reason the CherryMX model's didn't work so I would need to troubleshoot why the keycaps and switches are absent

Honest Note: I did use ChatGPT to help me understand the process when designing this PCB, along with helping me fix whatever errors I had. It also helped me take screenshots as my windows computer wouldn't let me on my wireless keyboard, therefore the blue cursor in several screenshots.

The next hour-ish (1-1.5) I've dedicated to creating firmware, I used Python ( a language I am quite good at ) using KMK, which runs on the CircuitPython on the Raspberry Pi Pico. I configured Matrix Wiring, Diode Direction, Key Layout, Fn Layer, USB Keyboard mode. I then ran desktop simulations for typing, wrote and tested the firmware files.

After this I spent the next 0.5 hour updating everything to github, and pushing changes to get stuff done.

### 2026-10-07 – October 8

**7h**

October 8

I had a new idea, what if we move the extra space on top and the pico a better spot to take less space. This would also look cleaner in the overall design


This change reduce the size 295x100mm and the Pico is now underneath the keyboard, with the USB facing left to connect to the PC. I thought about this so to make it cleaner, the Pico was moved facing the USB to the top. But this caused another problem, the Pico header pins ran into the switch mounting areas, so the cleanest solution was to keep the Pico underneath and use a short USB extension to a port on the case's edge above the number keys. Or we could create a short recessed pocket underneath the keyboard which works equally as well


The next step was to rotate the underside Pico inward. To do this I positioned it's USB port toward the keyboard's center and check clearance around the switch pins


I then had to reroute the controller connections, by reconnecting the matrix and reset circuit after changing the Pico orientation.


Nest I had to plan the USB pocket and cable channel by drawing the proposed case opened and space for insert the plug with the cable exiting above the number keys.


Then I had to refill the copper zones and run DRC, for which I had to fix any clearance or connection errors introduced by the changes and then capture the following results in the JSON report.


Finally I had to take a look at the updated underside in 3D to check on the controller placement and export new Gerbers and drill files for the new and revised board.


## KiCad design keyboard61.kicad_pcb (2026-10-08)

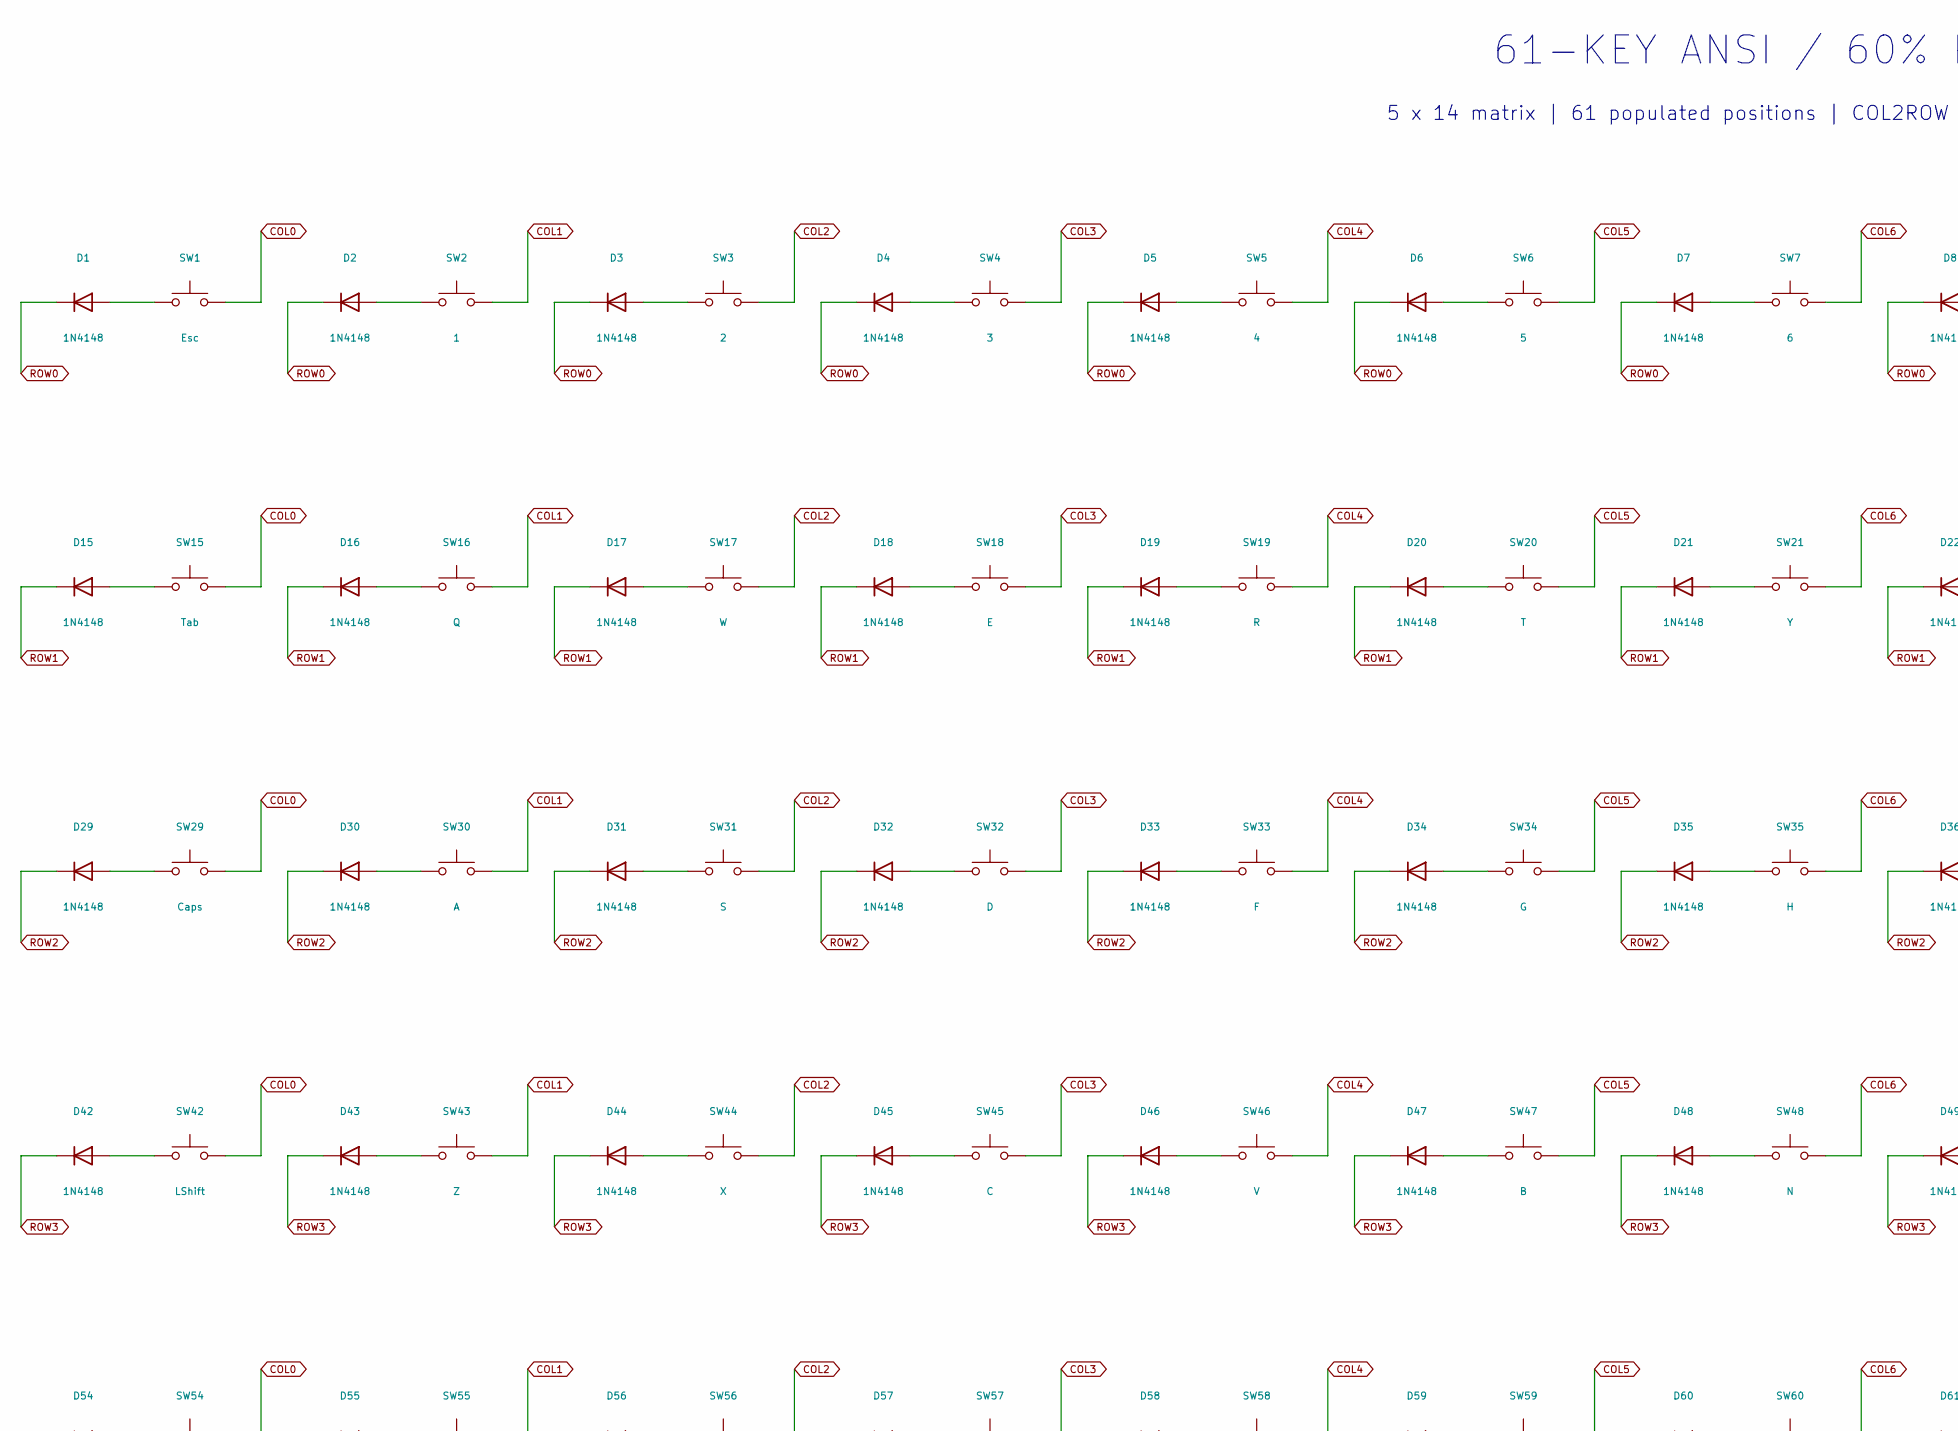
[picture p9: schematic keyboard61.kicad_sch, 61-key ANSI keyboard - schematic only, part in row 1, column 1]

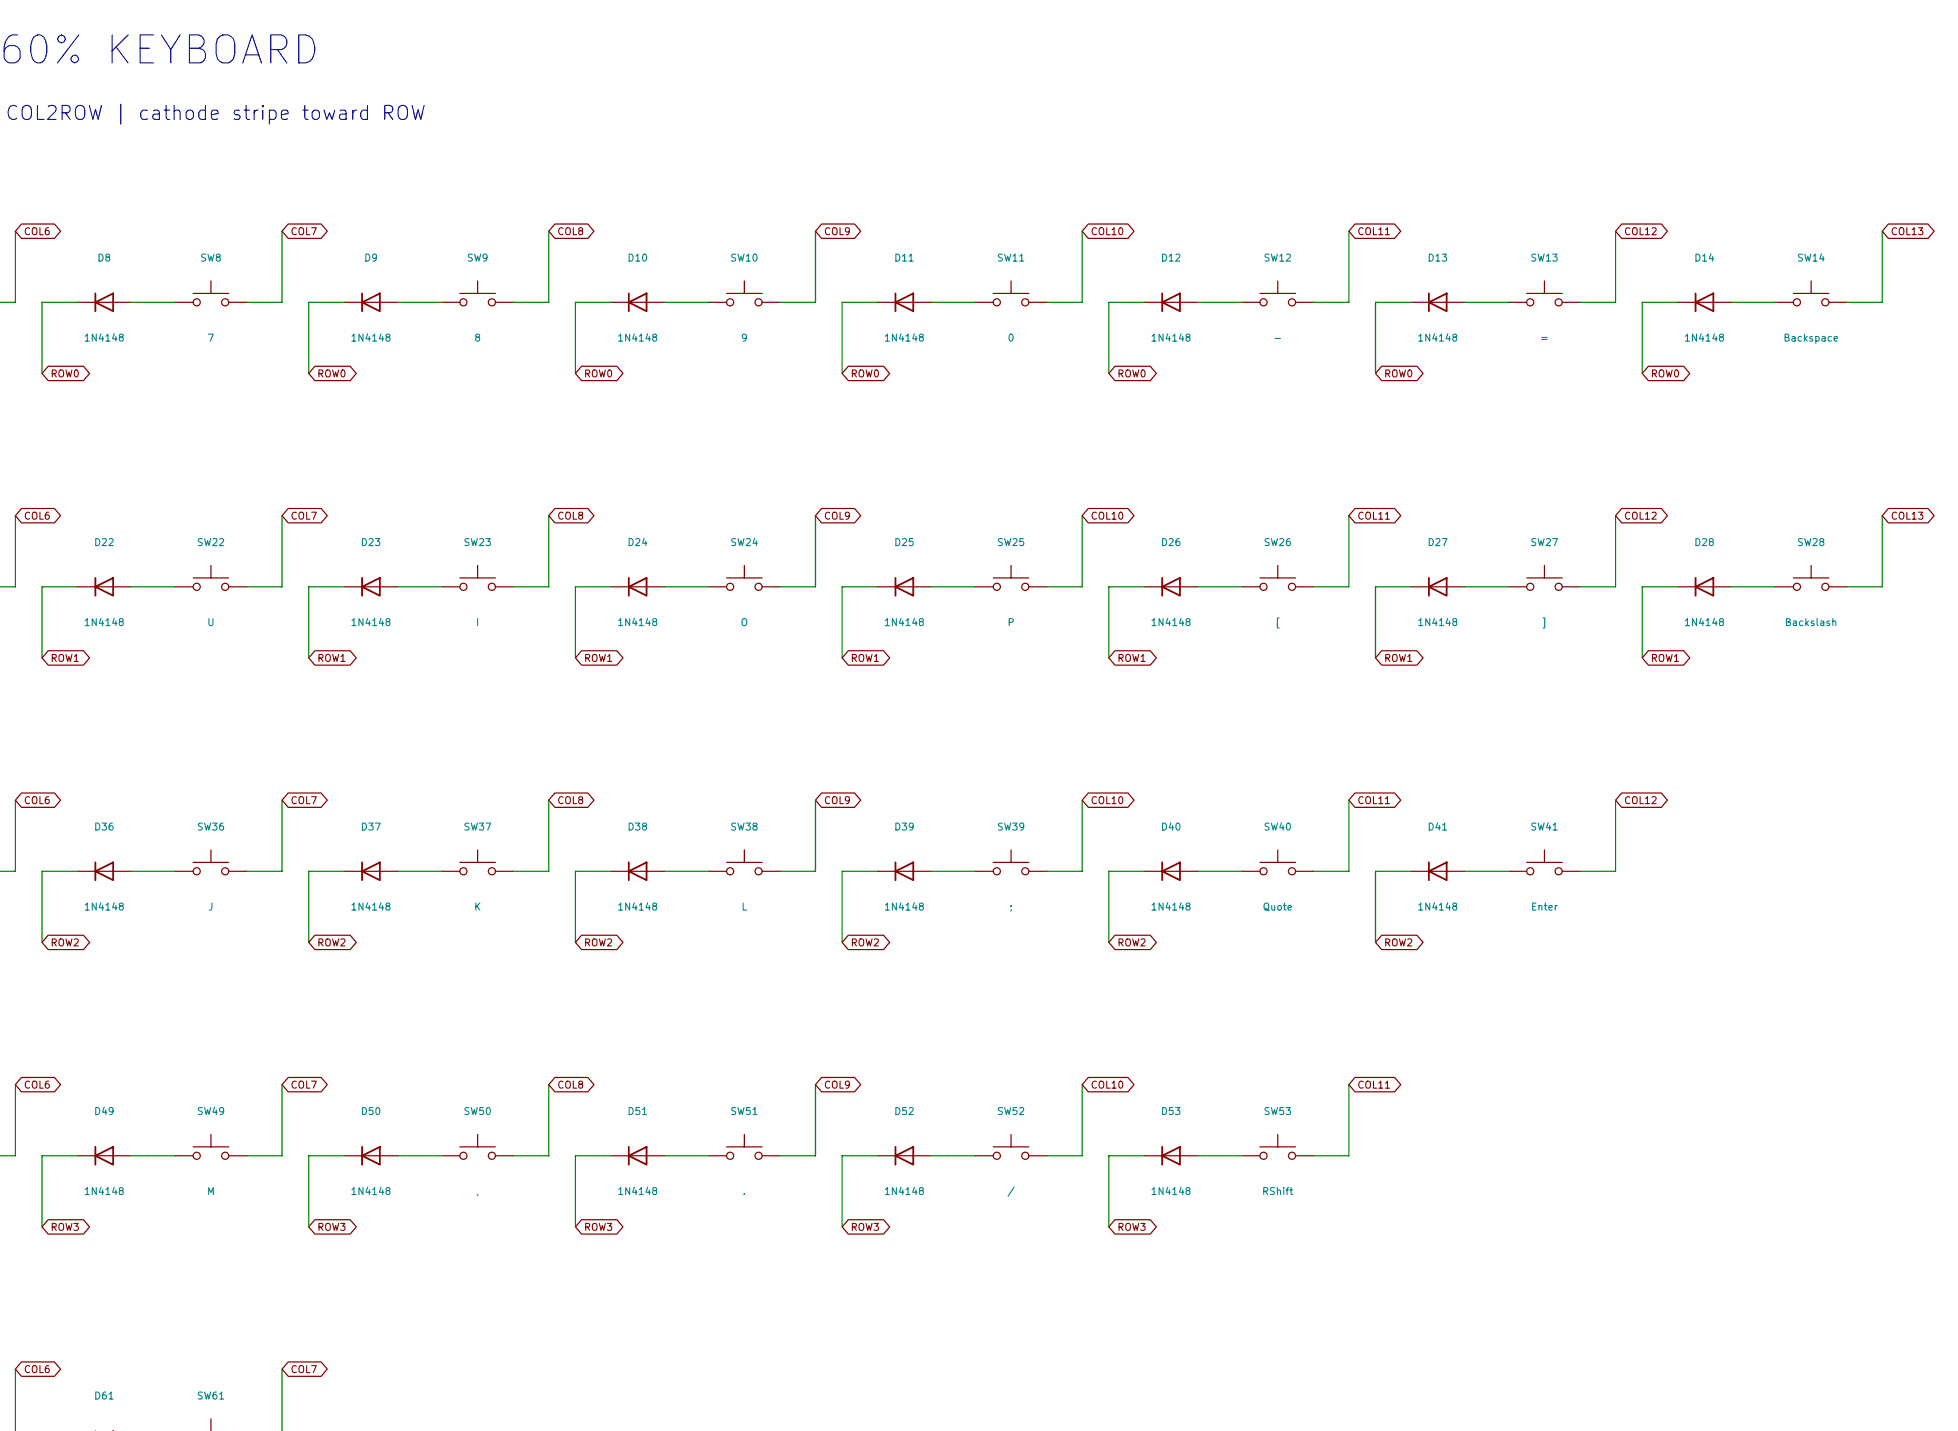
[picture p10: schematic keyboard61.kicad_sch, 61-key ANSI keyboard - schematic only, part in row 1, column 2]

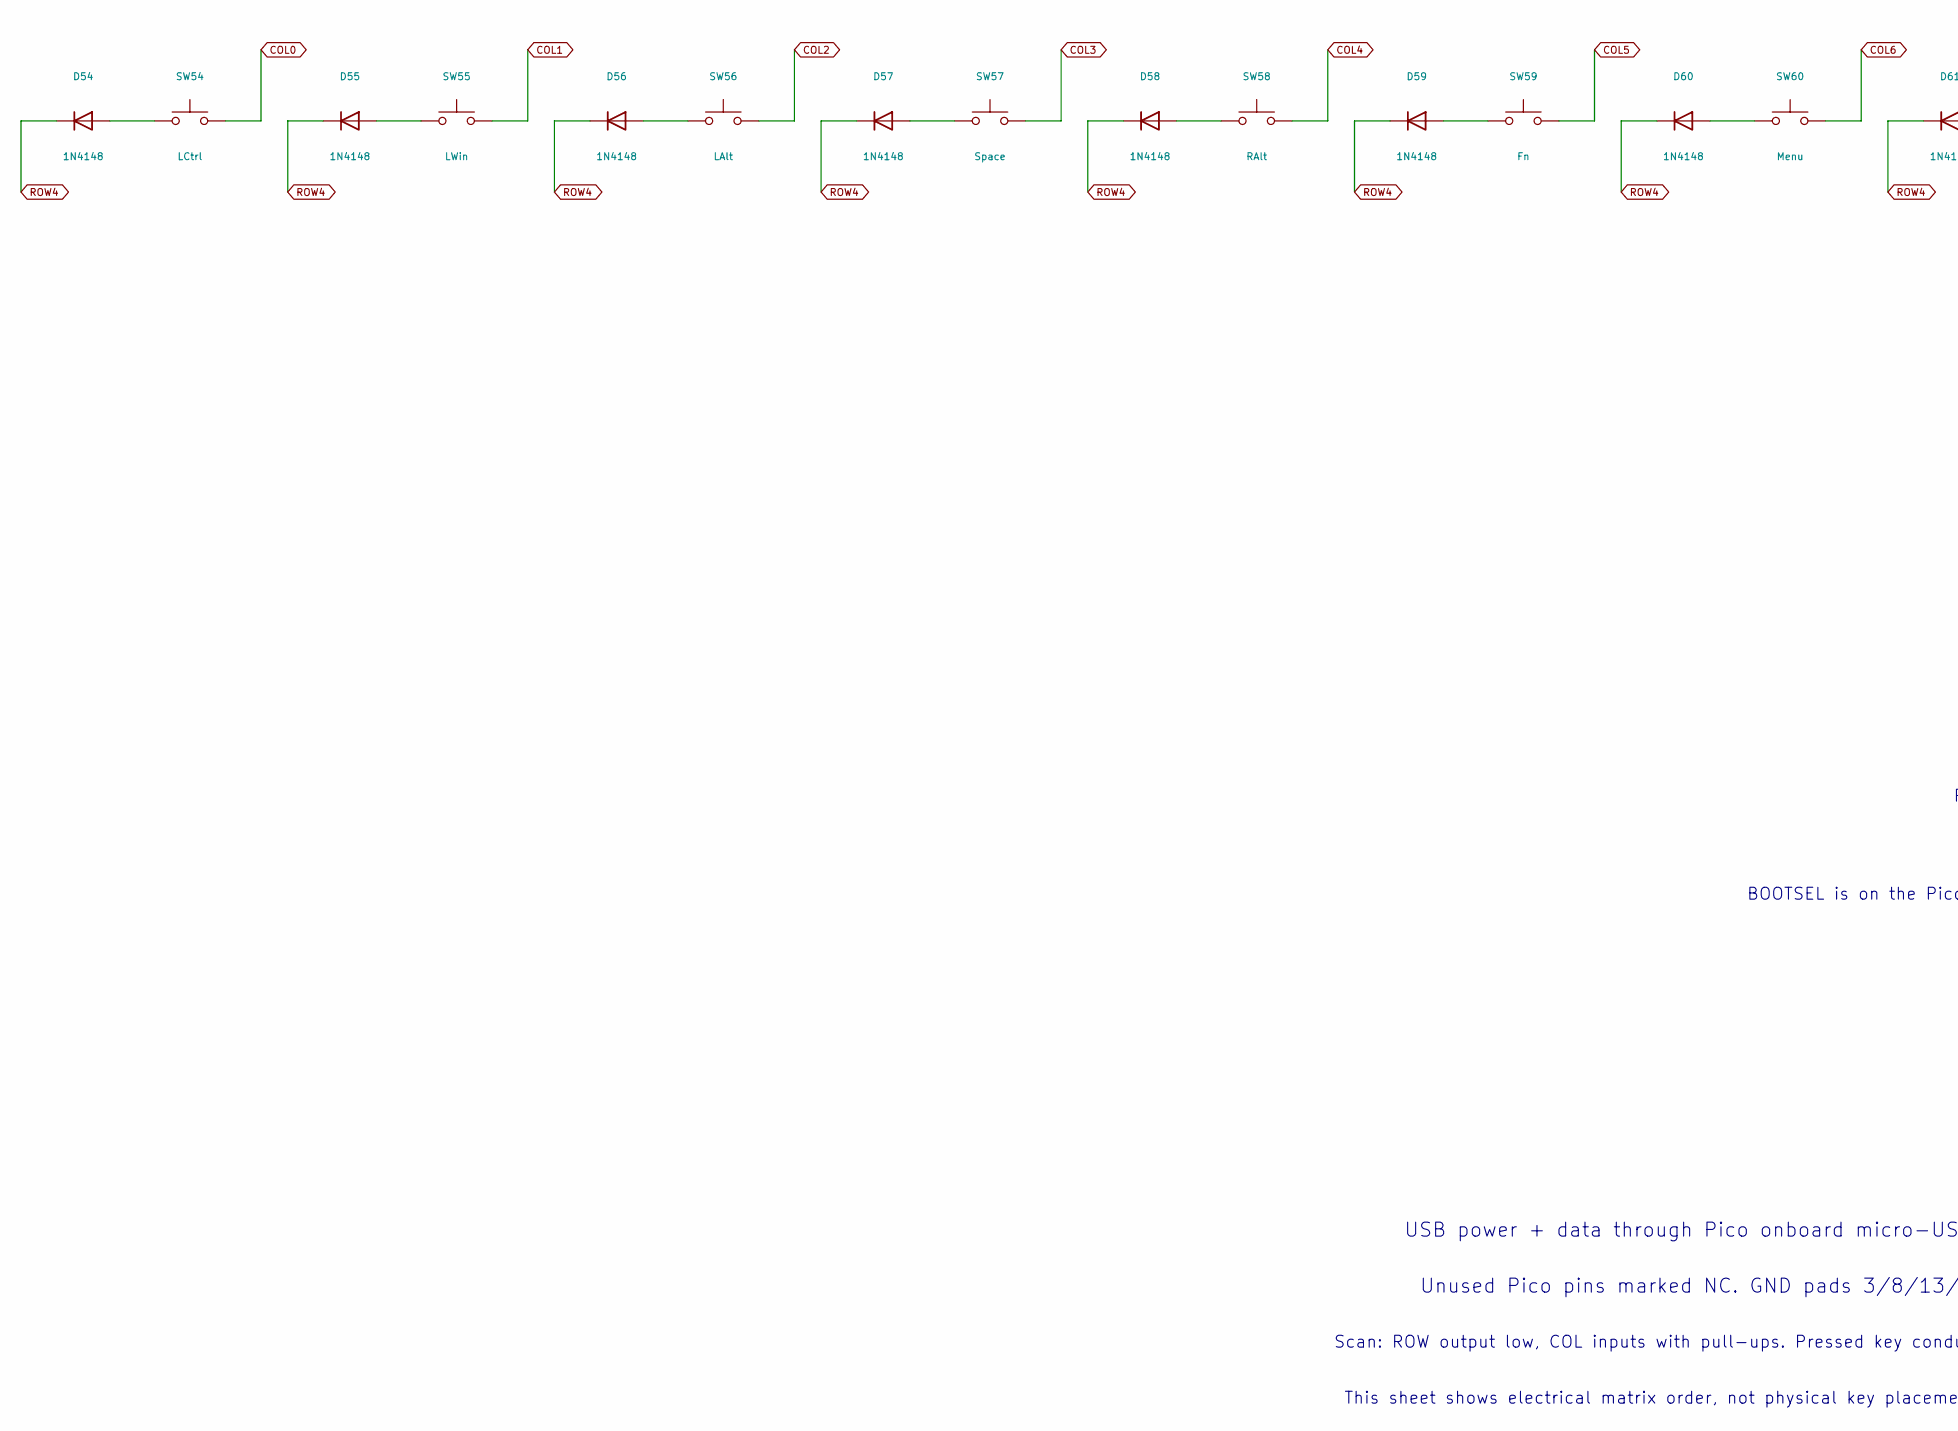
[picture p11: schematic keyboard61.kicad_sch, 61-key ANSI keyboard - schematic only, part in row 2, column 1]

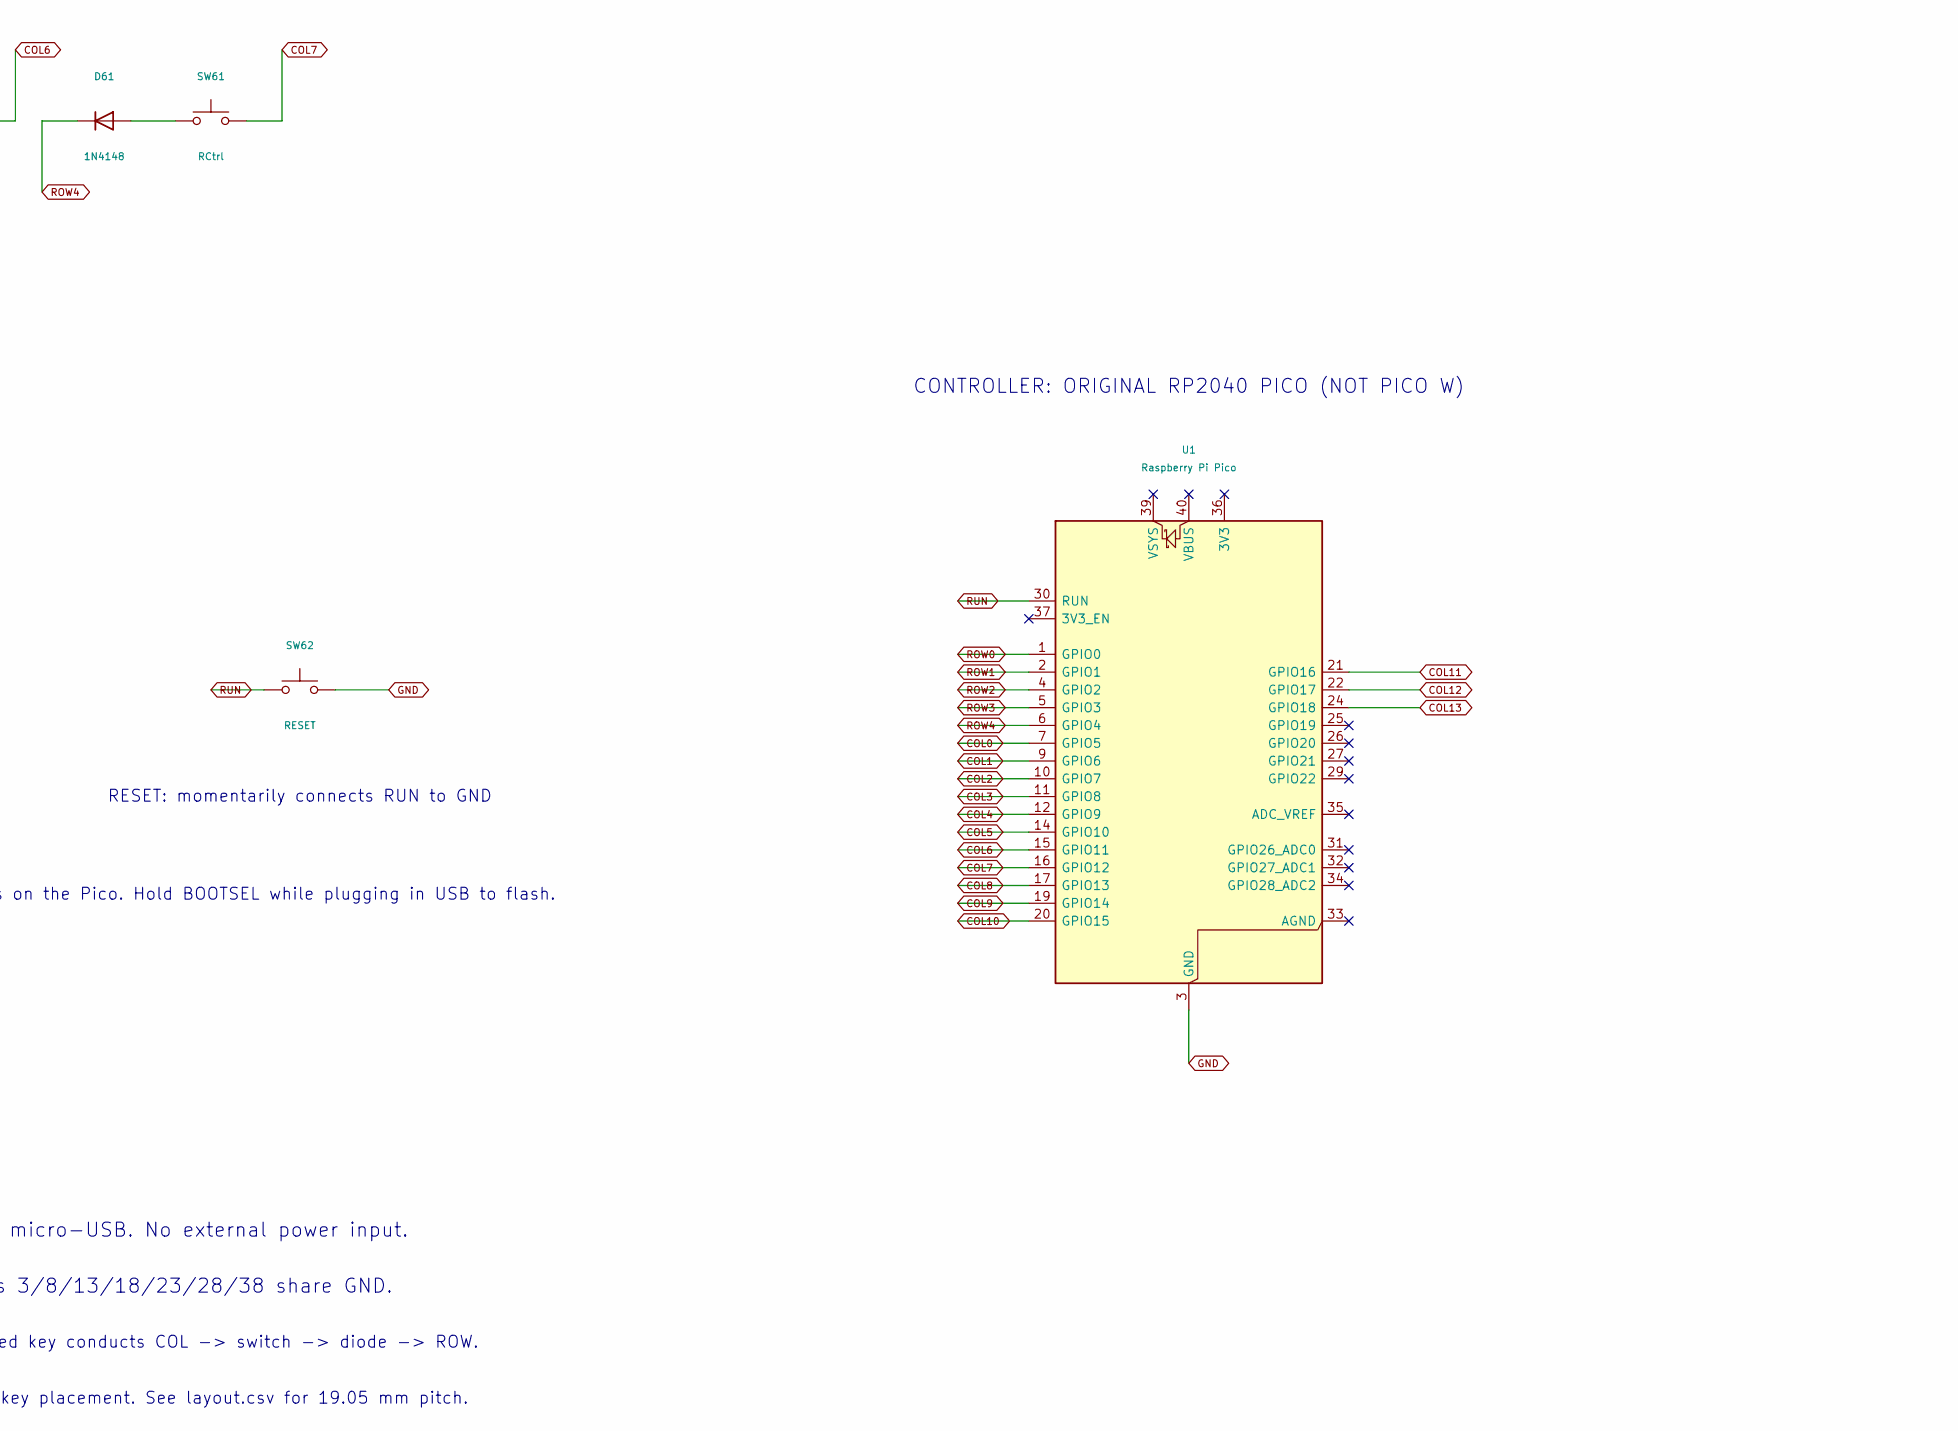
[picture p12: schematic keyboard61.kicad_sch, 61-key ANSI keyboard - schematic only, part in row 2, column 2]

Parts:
D1, D2, D3, D4, D5, D6, D7, D8, D9, D10, D11, D12, D13, D14, D15, D16, D17, D18, D19, D20, D21, D22, D23, D24, D25, D26, D27, D28, D29, D30, D31, D32, D33, D34, D35, D36, D37, D38, D39, D40, D41, D42, D43, D44, D45, D46, D47, D48, D49, D50, D51, D52, D53, D54, D55, D56, D57, D58, D59, D60, D61: 1N4148; D_DO-35_SOD27_P7.62mm_Horizontal
SW1: Esc; SW_Cherry_MX_1.00u_PCB
SW2: 1; SW_Cherry_MX_1.00u_PCB
SW3: 2; SW_Cherry_MX_1.00u_PCB
SW4: 3; SW_Cherry_MX_1.00u_PCB
SW5: 4; SW_Cherry_MX_1.00u_PCB
SW6: 5; SW_Cherry_MX_1.00u_PCB
SW7: 6; SW_Cherry_MX_1.00u_PCB
SW8: 7; SW_Cherry_MX_1.00u_PCB
SW9: 8; SW_Cherry_MX_1.00u_PCB
SW10: 9; SW_Cherry_MX_1.00u_PCB
SW11: 0; SW_Cherry_MX_1.00u_PCB
SW12: -; SW_Cherry_MX_1.00u_PCB
SW13: =; SW_Cherry_MX_1.00u_PCB
SW14: Backspace; SW_Cherry_MX_2.00u_PCB
SW15: Tab; SW_Cherry_MX_1.50u_PCB_SocketClearance
SW16: Q; SW_Cherry_MX_1.00u_PCB_SocketClearance
SW17: W; SW_Cherry_MX_1.00u_PCB
SW18: E; SW_Cherry_MX_1.00u_PCB
SW19: R; SW_Cherry_MX_1.00u_PCB
SW20: T; SW_Cherry_MX_1.00u_PCB
SW21: Y; SW_Cherry_MX_1.00u_PCB
SW22: U; SW_Cherry_MX_1.00u_PCB
SW23: I; SW_Cherry_MX_1.00u_PCB
SW24: O; SW_Cherry_MX_1.00u_PCB
SW25: P; SW_Cherry_MX_1.00u_PCB
SW26: [; SW_Cherry_MX_1.00u_PCB
SW27: ]; SW_Cherry_MX_1.00u_PCB
SW28: Backslash; SW_Cherry_MX_1.50u_PCB
SW29: Caps; SW_Cherry_MX_1.75u_PCB
SW30: A; SW_Cherry_MX_1.00u_PCB
SW31: S; SW_Cherry_MX_1.00u_PCB
SW32: D; SW_Cherry_MX_1.00u_PCB
SW33: F; SW_Cherry_MX_1.00u_PCB
SW34: G; SW_Cherry_MX_1.00u_PCB
SW35: H; SW_Cherry_MX_1.00u_PCB
SW36: J; SW_Cherry_MX_1.00u_PCB
SW37: K; SW_Cherry_MX_1.00u_PCB
SW38: L; SW_Cherry_MX_1.00u_PCB
SW39: ;; SW_Cherry_MX_1.00u_PCB
SW40: Quote; SW_Cherry_MX_1.00u_PCB
SW41: Enter; SW_Cherry_MX_2.25u_PCB
SW42: LShift; SW_Cherry_MX_2.25u_PCB
SW43: Z; SW_Cherry_MX_1.00u_PCB
SW44: X; SW_Cherry_MX_1.00u_PCB
SW45: C; SW_Cherry_MX_1.00u_PCB
SW46: V; SW_Cherry_MX_1.00u_PCB
SW47: B; SW_Cherry_MX_1.00u_PCB
SW48: N; SW_Cherry_MX_1.00u_PCB
SW49: M; SW_Cherry_MX_1.00u_PCB
SW50: ,; SW_Cherry_MX_1.00u_PCB
SW51: .; SW_Cherry_MX_1.00u_PCB
SW52: /; SW_Cherry_MX_1.00u_PCB
SW53: RShift; SW_Cherry_MX_2.75u_PCB
SW54: LCtrl; SW_Cherry_MX_1.25u_PCB
SW55: LWin; SW_Cherry_MX_1.25u_PCB
SW56: LAlt; SW_Cherry_MX_1.25u_PCB
SW57: Space; SW_Cherry_MX_6.25u_PCB
SW58: RAlt; SW_Cherry_MX_1.25u_PCB
SW59: Fn; SW_Cherry_MX_1.25u_PCB
SW60: Menu; SW_Cherry_MX_1.25u_PCB
SW61: RCtrl; SW_Cherry_MX_1.25u_PCB
SW62: RESET; SW_PUSH_6mm
U1: Raspberry Pi Pico; Pico_H_Bottom_Sockets_8_5mm

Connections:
COL0: SW1.2, SW15.2, SW29.2, SW42.2, SW54.2, U1.7 (GPIO5)
COL1: SW2.2, SW16.2, SW30.2, SW43.2, SW55.2, U1.9 (GPIO6)
COL2: SW3.2, SW17.2, SW31.2, SW44.2, SW56.2, U1.10 (GPIO7)
COL3: SW4.2, SW18.2, SW32.2, SW45.2, SW57.2, U1.11 (GPIO8)
COL4: SW5.2, SW19.2, SW33.2, SW46.2, SW58.2, U1.12 (GPIO9)
COL5: SW6.2, SW20.2, SW34.2, SW47.2, SW59.2, U1.14 (GPIO10)
COL6: SW7.2, SW21.2, SW35.2, SW48.2, SW60.2, U1.15 (GPIO11)
COL7: SW8.2, SW22.2, SW36.2, SW49.2, SW61.2, U1.16 (GPIO12)
COL8: SW9.2, SW23.2, SW37.2, SW50.2, U1.17 (GPIO13)
COL9: SW10.2, SW24.2, SW38.2, SW51.2, U1.19 (GPIO14)
COL10: SW11.2, SW25.2, SW39.2, SW52.2, U1.20 (GPIO15)
COL11: SW12.2, SW26.2, SW40.2, SW53.2, U1.21 (GPIO16)
COL12: SW13.2, SW27.2, SW41.2, U1.22 (GPIO17)
COL13: SW14.2, SW28.2, U1.24 (GPIO18)
GND: SW62.2, U1.3 (GND), U1.8 (GND), U1.13 (GND), U1.18 (GND), U1.23 (GND), U1.28 (GND), U1.38 (GND)
unnamed: D1.2 (A), SW1.1
unnamed: D2.2 (A), SW2.1
unnamed: D3.2 (A), SW3.1
unnamed: D4.2 (A), SW4.1
unnamed: D5.2 (A), SW5.1
unnamed: D6.2 (A), SW6.1
unnamed: D7.2 (A), SW7.1
unnamed: D8.2 (A), SW8.1
unnamed: D9.2 (A), SW9.1
unnamed: D10.2 (A), SW10.1
unnamed: D11.2 (A), SW11.1
unnamed: D12.2 (A), SW12.1
unnamed: D13.2 (A), SW13.1
unnamed: D14.2 (A), SW14.1
unnamed: D15.2 (A), SW15.1
unnamed: D16.2 (A), SW16.1
unnamed: D17.2 (A), SW17.1
unnamed: D18.2 (A), SW18.1
unnamed: D19.2 (A), SW19.1
unnamed: D20.2 (A), SW20.1
unnamed: D21.2 (A), SW21.1
unnamed: D22.2 (A), SW22.1
unnamed: D23.2 (A), SW23.1
unnamed: D24.2 (A), SW24.1
unnamed: D25.2 (A), SW25.1
unnamed: D26.2 (A), SW26.1
unnamed: D27.2 (A), SW27.1
unnamed: D28.2 (A), SW28.1
unnamed: D29.2 (A), SW29.1
unnamed: D30.2 (A), SW30.1
unnamed: D31.2 (A), SW31.1
unnamed: D32.2 (A), SW32.1
unnamed: D33.2 (A), SW33.1
unnamed: D34.2 (A), SW34.1
unnamed: D35.2 (A), SW35.1
unnamed: D36.2 (A), SW36.1
unnamed: D37.2 (A), SW37.1
unnamed: D38.2 (A), SW38.1
unnamed: D39.2 (A), SW39.1
unnamed: D40.2 (A), SW40.1
unnamed: D41.2 (A), SW41.1
unnamed: D42.2 (A), SW42.1
unnamed: D43.2 (A), SW43.1
unnamed: D44.2 (A), SW44.1
unnamed: D45.2 (A), SW45.1
unnamed: D46.2 (A), SW46.1
unnamed: D47.2 (A), SW47.1
unnamed: D48.2 (A), SW48.1
unnamed: D49.2 (A), SW49.1
unnamed: D50.2 (A), SW50.1
unnamed: D51.2 (A), SW51.1
unnamed: D52.2 (A), SW52.1
unnamed: D53.2 (A), SW53.1
unnamed: D54.2 (A), SW54.1
unnamed: D55.2 (A), SW55.1
unnamed: D56.2 (A), SW56.1
unnamed: D57.2 (A), SW57.1
unnamed: D58.2 (A), SW58.1
unnamed: D59.2 (A), SW59.1
unnamed: D60.2 (A), SW60.1
unnamed: D61.2 (A), SW61.1
ROW0: D1.1 (K), D2.1 (K), D3.1 (K), D4.1 (K), D5.1 (K), D6.1 (K), D7.1 (K), D8.1 (K), D9.1 (K), D10.1 (K), D11.1 (K), D12.1 (K), D13.1 (K), D14.1 (K), U1.1 (GPIO0)
ROW1: D15.1 (K), D16.1 (K), D17.1 (K), D18.1 (K), D19.1 (K), D20.1 (K), D21.1 (K), D22.1 (K), D23.1 (K), D24.1 (K), D25.1 (K), D26.1 (K), D27.1 (K), D28.1 (K), U1.2 (GPIO1)
ROW2: D29.1 (K), D30.1 (K), D31.1 (K), D32.1 (K), D33.1 (K), D34.1 (K), D35.1 (K), D36.1 (K), D37.1 (K), D38.1 (K), D39.1 (K), D40.1 (K), D41.1 (K), U1.4 (GPIO2)
ROW3: D42.1 (K), D43.1 (K), D44.1 (K), D45.1 (K), D46.1 (K), D47.1 (K), D48.1 (K), D49.1 (K), D50.1 (K), D51.1 (K), D52.1 (K), D53.1 (K), U1.5 (GPIO3)
ROW4: D54.1 (K), D55.1 (K), D56.1 (K), D57.1 (K), D58.1 (K), D59.1 (K), D60.1 (K), D61.1 (K), U1.6 (GPIO4)
RUN: SW62.1, U1.30 (RUN)

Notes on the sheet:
USB power + data through Pico onboard micro-USB. No external power input.
Unused Pico pins marked NC. GND pads 3/8/13/18/23/28/38 share GND.
61-KEY ANSI / 60% KEYBOARD
Scan: ROW output low, COL inputs with pull-ups. Pressed key conducts COL -> switch -> diode -> ROW.
BOOTSEL is on the Pico. Hold BOOTSEL while plugging in USB to flash.
5 x 14 matrix | 61 populated positions | COL2ROW | cathode stripe toward ROW
RESET: momentarily connects RUN to GND
CONTROLLER: ORIGINAL RP2040 PICO (NOT PICO W)
This sheet shows electrical matrix order, not physical key placement. See layout.csv for 19.05 mm pitch.

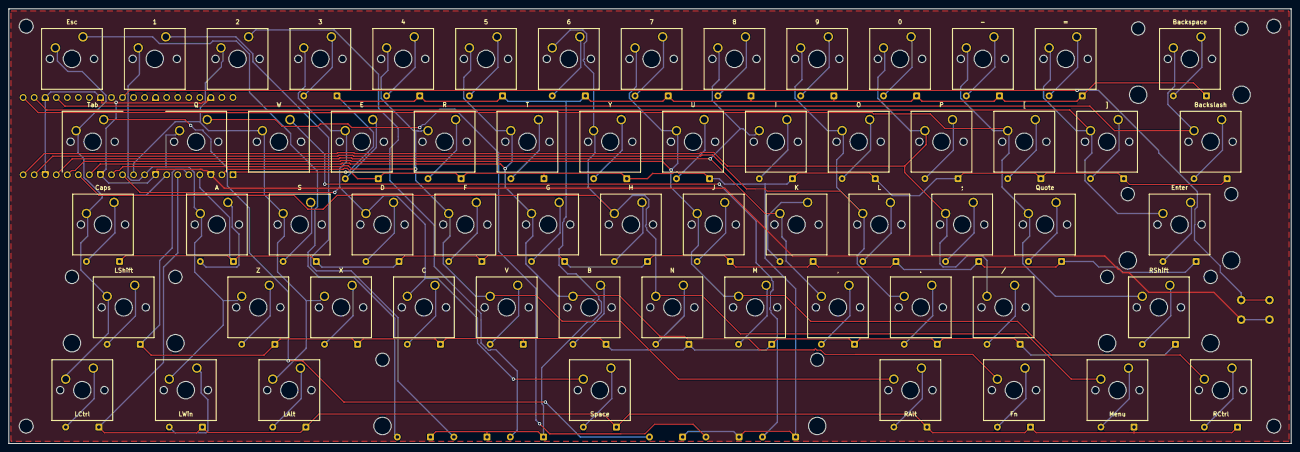
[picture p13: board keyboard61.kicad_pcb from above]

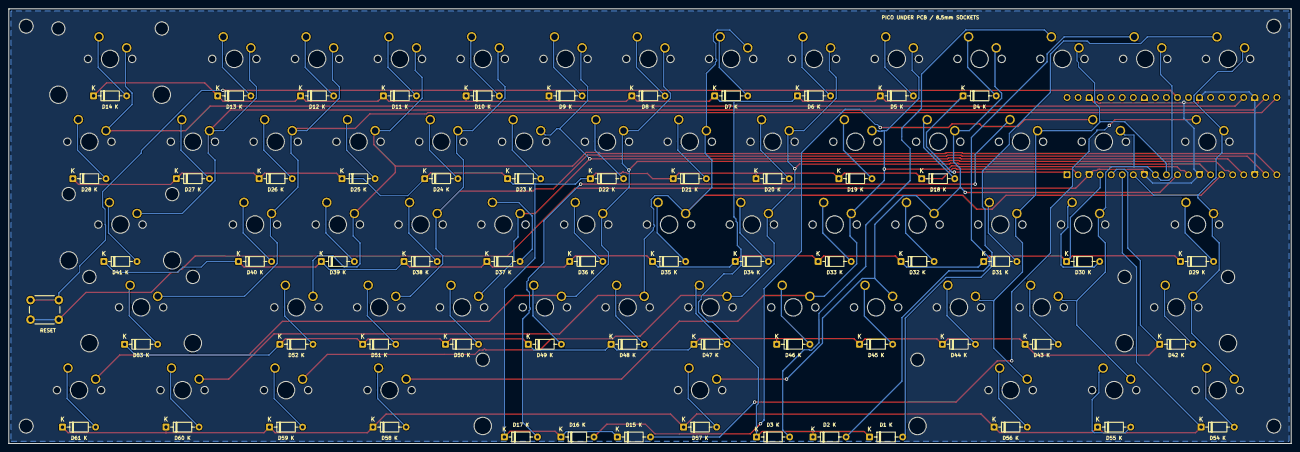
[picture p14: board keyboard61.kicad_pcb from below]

Board: 2 copper layers, 295.0 x 100.0 mm, 128 parts (63 on the bottom side), 82 nets.

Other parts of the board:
H1, H2, H3, H4: MountingHole_3.2mm_M3

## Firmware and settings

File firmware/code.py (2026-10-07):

import board

from kmk.kmk_keyboard import KMKKeyboard
from kmk.keys import KC, KeyboardKey, make_key
from kmk.modules.layers import Layers
from kmk.scanners import DiodeOrientation

keyboard = KMKKeyboard()
keyboard.row_pins = (board.GP0, board.GP1, board.GP2, board.GP3, board.GP4)
keyboard.col_pins = (
    board.GP5, board.GP6, board.GP7, board.GP8, board.GP9, board.GP10, board.GP11,
    board.GP12, board.GP13, board.GP14, board.GP15, board.GP16, board.GP17, board.GP18,
)
keyboard.diode_orientation = DiodeOrientation.COL2ROW
keyboard.modules.append(Layers())
make_key(names=('APP',), constructor=KeyboardKey, code=0x65)

keyboard.keymap = [
    [
        KC.ESC, KC.N1, KC.N2, KC.N3, KC.N4, KC.N5, KC.N6, KC.N7, KC.N8, KC.N9, KC.N0, KC.MINS, KC.EQL, KC.BSPC,
        KC.TAB, KC.Q, KC.W, KC.E, KC.R, KC.T, KC.Y, KC.U, KC.I, KC.O, KC.P, KC.LBRC, KC.RBRC, KC.BSLS,
        KC.CAPS, KC.A, KC.S, KC.D, KC.F, KC.G, KC.H, KC.J, KC.K, KC.L, KC.SCLN, KC.QUOT, KC.ENTER, KC.NO,
        KC.LSFT, KC.Z, KC.X, KC.C, KC.V, KC.B, KC.N, KC.M, KC.COMM, KC.DOT, KC.SLSH, KC.RSFT, KC.NO, KC.NO,
        KC.LCTL, KC.LGUI, KC.LALT, KC.SPACE, KC.RALT, KC.MO(1), KC.APP, KC.RCTL, KC.NO, KC.NO, KC.NO, KC.NO, KC.NO, KC.NO,
    ],
    [
        KC.GRV, KC.F1, KC.F2, KC.F3, KC.F4, KC.F5, KC.F6, KC.F7, KC.F8, KC.F9, KC.F10, KC.F11, KC.F12, KC.DEL,
        KC.TRNS, KC.TRNS, KC.TRNS, KC.TRNS, KC.TRNS, KC.TRNS, KC.TRNS, KC.HOME, KC.UP, KC.END, KC.PGUP, KC.TRNS, KC.TRNS, KC.TRNS,
        KC.TRNS, KC.TRNS, KC.TRNS, KC.TRNS, KC.TRNS, KC.TRNS, KC.TRNS, KC.LEFT, KC.DOWN, KC.RIGHT, KC.PGDN, KC.TRNS, KC.TRNS, KC.NO,
        KC.TRNS, KC.TRNS, KC.TRNS, KC.TRNS, KC.TRNS, KC.TRNS, KC.TRNS, KC.TRNS, KC.TRNS, KC.TRNS, KC.TRNS, KC.TRNS, KC.NO, KC.NO,
        KC.TRNS, KC.TRNS, KC.TRNS, KC.TRNS, KC.TRNS, KC.TRNS, KC.TRNS, KC.TRNS, KC.NO, KC.NO, KC.NO, KC.NO, KC.NO, KC.NO,
    ],
]

if __name__ == "__main__":
    keyboard.go()

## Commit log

2026-10-12 Create BOM
2026-10-17 Add functional volume knob and Week 2 CAD costs
2026-10-17 Sync Keyboard Case from Half Life
